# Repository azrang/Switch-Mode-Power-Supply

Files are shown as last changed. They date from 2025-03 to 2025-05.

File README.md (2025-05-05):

# Switch Mode Power Supply

This is a GitHub repo displaying all the files for the 2025 Cooper Union senior project, including the LTSpice simulations, firmware, testing procedures, and any final design files (block diagram, schematic, layout, etc.) for any boards manufactured. 

## Goals
The goal of this senior project is to make a Switch Mode Power Supply that can:
- Be SAFE (the 120V from the wall will be stepped down to 24V RMS using a transformer)
- Do AC-DC conversion so it can be used as a lab bench power supply
- Have 2 independent channels that range from 1-20V and 0-3A
- Support series and parallel mode for these channels
- Have a constant USB-C 5V 3A output
- Be power efficient
    - Based on the lab bench Gwinstek SMPS SPD-3606, a good target efficiency is 50%
- Low voltage ripple (<1%)

## Circuitry
Some of the circuitry for the project include:
- Safety Circuits
    - Common mode choke
    - Zener diodes
    - OVP
    - OCP
    - UVP
- Diode Rectifier
- Flyback converter
- Buck converter
- Opto-Isolators
- Power MOSFETs and power relays
- USB-C controller
- Feedback loop using an error amplifier
- 3 isolated grounds

## Firmware
Two ESP32 Dev Modules processing feedback and driving the circuit.

# Contributors
This project was done by a group of three friends:
- Azra Rangwala (EE'25)
- Ilona Lameka (EE'25)
- Ridwan Hussain (EE'25)

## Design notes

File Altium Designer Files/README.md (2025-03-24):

These are files from the Altium Designer for the Schematic and the Layout. 

- The "Board Information Report.txt" contains has information on the total number of components (352), connections (753), cooper utilization (87%, 91%, 92%, 92%), number of vias (289), etc.
- The "Project Outputs for SMPS.zip" is a final with all the gerber files that can be used to fabricate the board to manufacture the board. The settings chosen are specifically for JLC PCB.
- The "SMPS.zip" contains the Altium files (schematic, layout, etc.).
- The schematic was exported to the "SMPS_Schematic.pdf" file as a SmartPDF from Altium Designer so the nets are active links. 

# Layout
## Components 
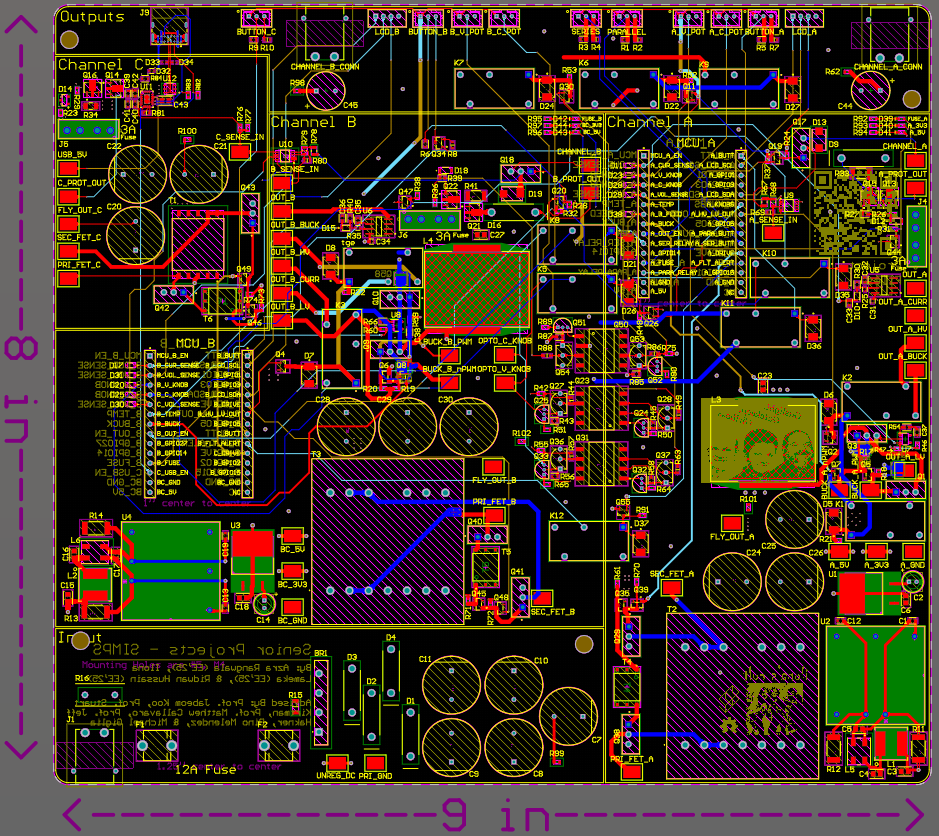
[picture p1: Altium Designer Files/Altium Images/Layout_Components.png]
Layout_Components


This image shows all the components and all the traces on the board.

## Top Layer
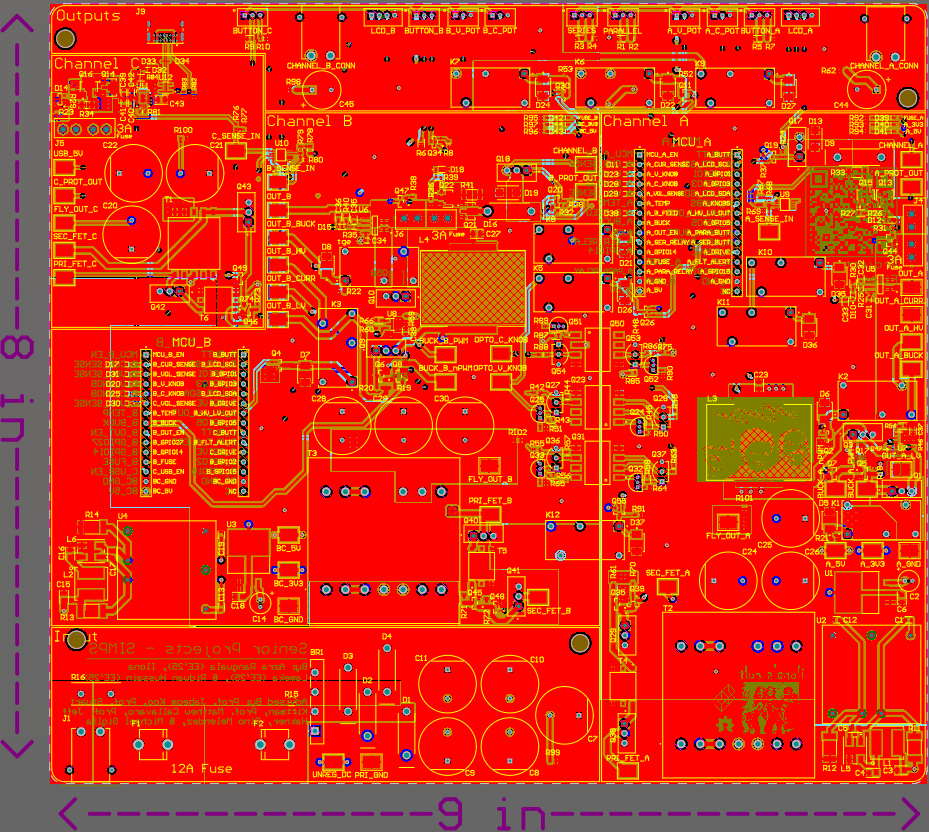
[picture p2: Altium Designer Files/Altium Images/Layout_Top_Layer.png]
Layout_Top_Layer


This image shows all of the top layer polygon pours.

## Layer 1
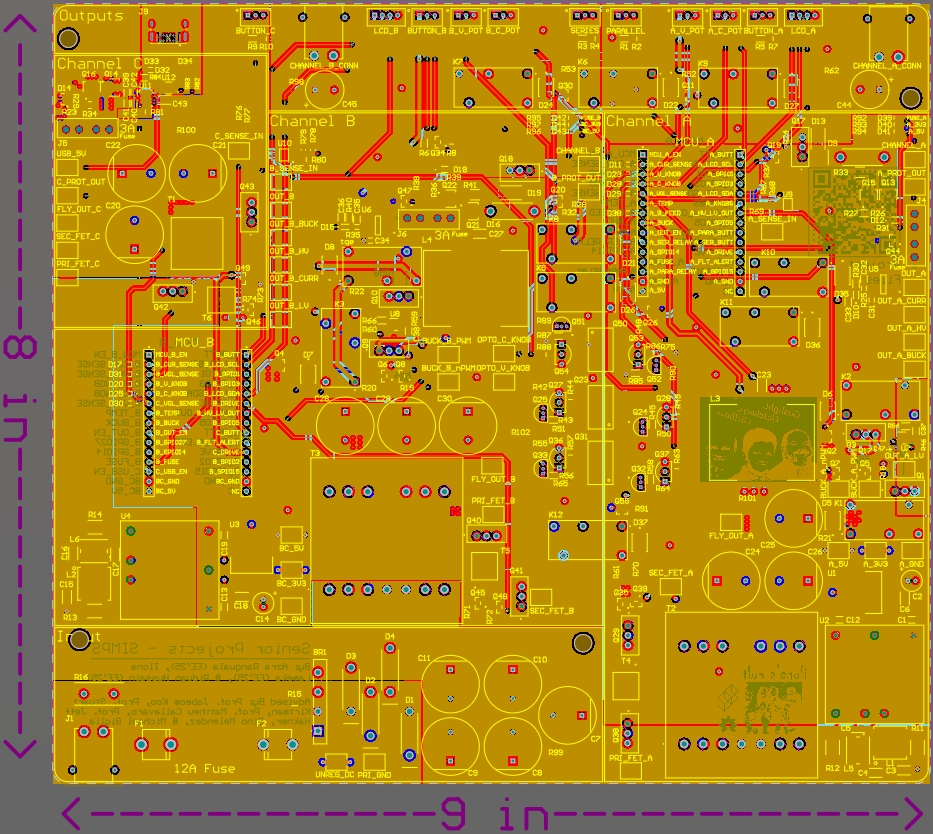
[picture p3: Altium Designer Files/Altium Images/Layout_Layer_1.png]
Layout_Layer_1


This image shows all of the layer 1 polygon pours.

## Layer 2
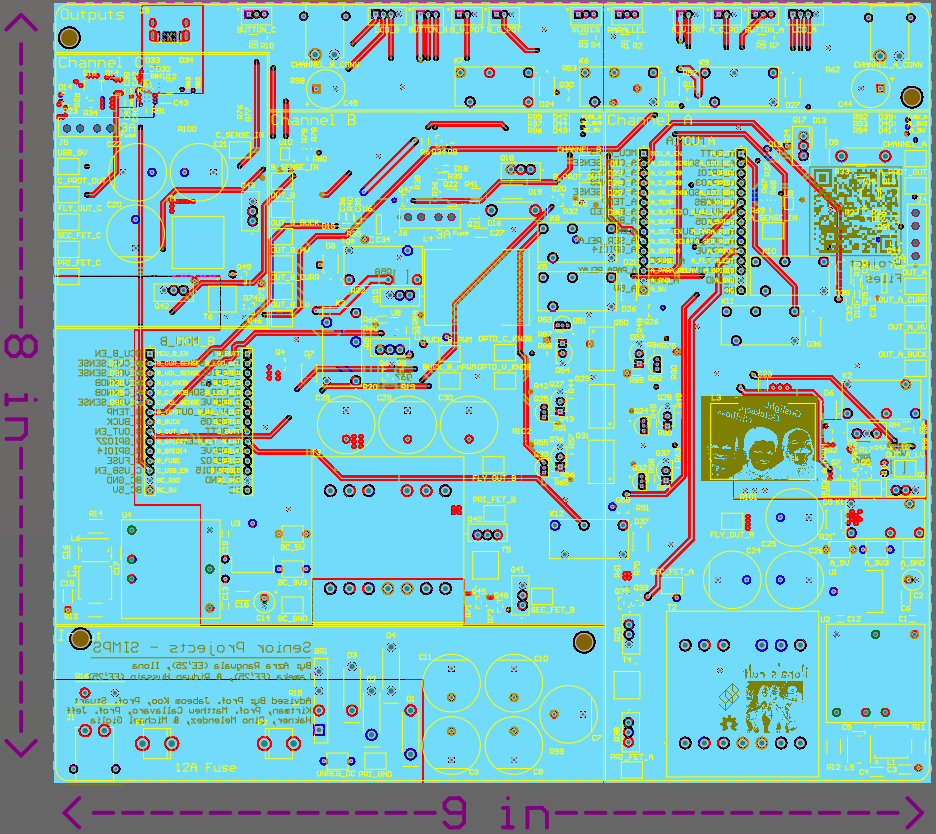
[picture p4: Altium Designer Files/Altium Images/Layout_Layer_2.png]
Layout_Layer_2


This image shows all of the layer 2 polygon pours.

## Bottom Layer
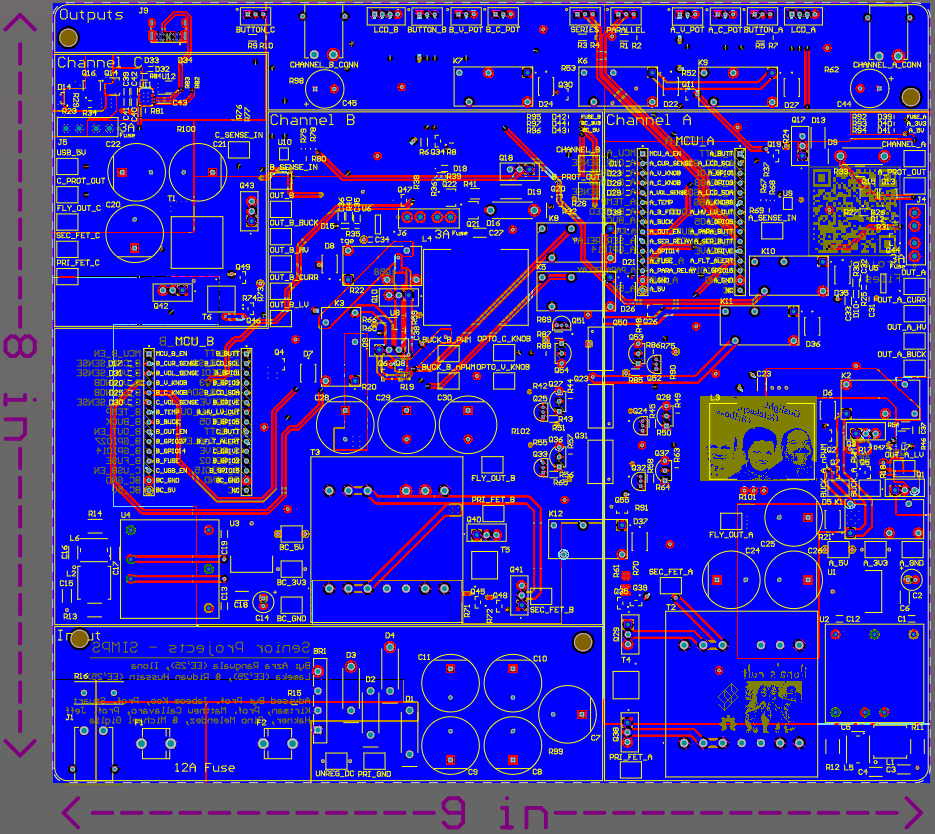
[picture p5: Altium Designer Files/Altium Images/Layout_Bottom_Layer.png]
Layout_Bottom_Layer


This image shows all of the bottom layer polygon pours.

## Top 3D View
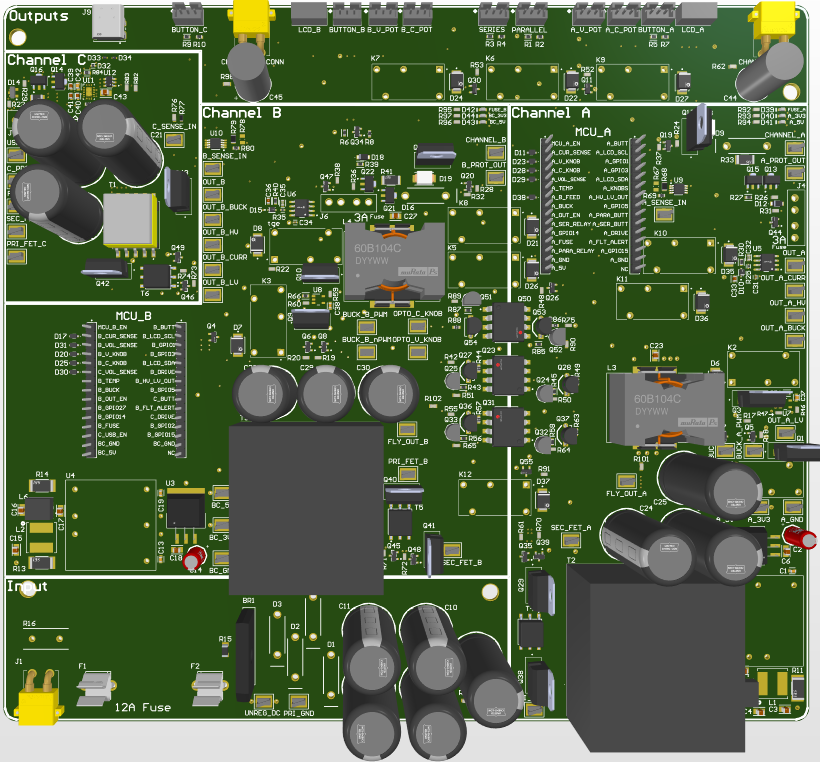
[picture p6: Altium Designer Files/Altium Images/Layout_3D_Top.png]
Layout_3D


This image shows the top 3D view of the board.

## Bottom 3D View
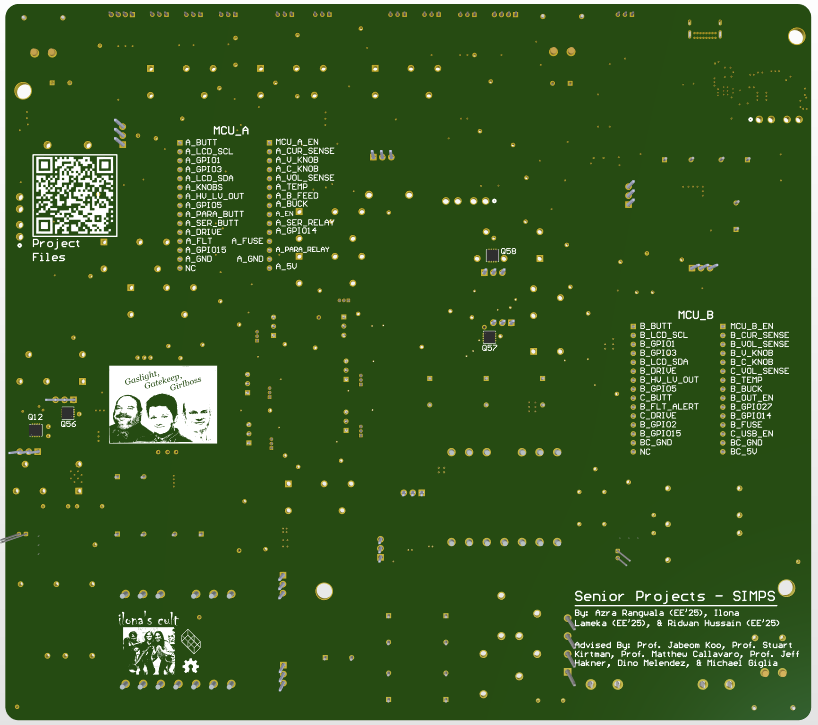
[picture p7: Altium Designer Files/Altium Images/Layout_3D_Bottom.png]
Layout_3D


This image shows the bottom 3D view of the board.

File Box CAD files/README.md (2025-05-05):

Onshape was used to design the CAD files for the box. 

1/4" clear acrylic was used.

Holes were cut to attach potentiometers, on/off buttons, LED screens, hinges, USBC port, etc.

A composite MDF base was used and the PCB was mounted on top of it. 

Here are the links to the onshape files:
- Top of Box: https://cad.onshape.com/documents/0df582968d671b375b7a9c29/w/103cd2e1ee54d52b4b8c83c5/e/ac7fc15e7fd9a07d4809bed0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 
- Sides: https://cad.onshape.com/documents/e65f365ee89599609901dbe1/w/213f92301eba854fda493029/e/9b6b9b5771b2472295cb6f8d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
- Front: https://cad.onshape.com/documents/9a4ddbb278e80e80a4dc2e93/w/c44b34705e7752b6a0ac6f8c/e/1b580939460691cddf3861bc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
- Back: https://cad.onshape.com/documents/6ed11a308b0e974dd588e9f7/w/b1c8eb4ebaca73d462ef1e77/e/57a0dc20c3867b08949bc04d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

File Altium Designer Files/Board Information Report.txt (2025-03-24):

Board Information Report
Date         : 3/23/2025
Time         : 5:12:02 PM
Time Elapsed : 00:00:01

General
    Board Size, 8999.997milsx7999.995mils
    Components on board, 352
count : 2

Routing Information
    Routing completion, 100.00%
    Connections, 753
    Connections routed, 753
    Connections remaining, 0
count : 4

Layer, Arcs, Pads, Vias, Tracks, Texts, Fills, Regions, ComponentBodies
    Top Layer, 0, 601, 0, 1095, 0, 0, 400, 0
    Layer 1, 0, 0, 0, 185, 0, 0, 51, 0
    Layer 2, 0, 0, 0, 172, 0, 0, 41, 0
    Bottom Layer, 0, 32, 0, 243, 0, 0, 74, 0
    Mechanical 1, 4, 0, 0, 4, 2, 0, 0, 27
    Top Assembly, 0, 0, 0, 496, 144, 0, 0, 3
    Bottom Assembly, 0, 0, 0, 0, 0, 0, 0, 0
    Top 3D Body, 14, 0, 0, 497, 0, 0, 0, 143
    Top Courtyard, 30, 0, 0, 514, 0, 0, 0, 0
    Bottom Courtyard, 0, 0, 0, 0, 0, 0, 0, 0
    Top Designator, 0, 0, 0, 0, 5, 0, 0, 0
    Bottom Designator, 0, 0, 0, 0, 0, 0, 0, 0
    Mechanical 10, 0, 0, 0, 24, 6, 0, 0, 0
    Top Component Outline, 7, 0, 0, 66, 0, 0, 2, 0
    Bottom Component Outline, 0, 0, 0, 24, 0, 0, 0, 0
    Mechanical 13, 57, 0, 0, 989, 2, 0, 0, 510
    Mechanical 15, 2, 0, 0, 1082, 0, 0, 20, 0
    Top Component Center, 0, 0, 0, 280, 0, 0, 0, 0
    Mechanical 20, 0, 0, 0, 12, 0, 0, 0, 0
    Bottom 3D Body, 0, 0, 0, 0, 0, 0, 0, 0
    Bottom Component Center, 0, 0, 0, 0, 0, 0, 0, 0
    Multi-Layer, 0, 367, 289, 0, 0, 0, 1, 0
    Top Paste, 0, 0, 0, 0, 0, 0, 2, 0
    Top Overlay, 160, 0, 0, 998, 780, 0, 0, 0
    Top Solder, 0, 0, 0, 0, 0, 0, 0, 0
    Bottom Solder, 0, 0, 0, 0, 0, 0, 4, 0
    Bottom Overlay, 3, 0, 0, 29, 78, 0, 1698, 0
    Bottom Paste, 0, 0, 0, 0, 0, 0, 4, 0
    Drill Guide, 0, 0, 0, 0, 0, 0, 0, 0
    Keep-Out Layer, 0, 0, 0, 0, 0, 0, 0, 0
    Drill Drawing, 0, 0, 0, 0, 0, 0, 0, 0
count : 31

Drill Pairs, Vias
    Top Layer - Bottom Layer, 289
count : 1

Layer, Sq.In., Sq.MM., Percent of layer
    Top Layer, 62.906, 40584.728, 87%
    Layer 1, 65.621, 42336.054, 91%
    Layer 2, 65.983, 42569.855, 92%
    Bottom Layer, 65.941, 42542.417, 92%
count : 4

Non-Plated Hole Size, Pads, Vias
    0mils, 48, 0
count : 1

Plated Hole Size, Pads, Vias
    0mils, 585, 0
    11.811mils, 0, 25
    15mils, 0, 173
    15.748mils, 16, 0
    20mils, 0, 6
    28mils, 0, 15
    30mils, 0, 64
    31.496mils, 49, 0
    35mils, 0, 2
    35.433mils, 4, 0
    37.402mils, 46, 0
    39.37mils, 14, 0
    40.158mils, 60, 0
    45mils, 12, 0
    50mils, 38, 0
    51.181mils, 60, 0
    57.48mils, 4, 0
    62.992mils, 26, 0
    65mils, 24, 0
    66.929mils, 6, 0
    77.953mils, 4, 0
    177.165mils, 0, 4
count : 22

Non-Plated Slot Size / Length, Pads
count : 0

Plated Slot Size / Length, Pads
    55.118mil / 23.622mil, 2
    82.677mil / 23.622mil, 2
count : 2

Non-Plated Square Hole Size, Pads
count : 0

Plated Square Hole Size, Pads
count : 0

Top Layer Annular Ring Size, Count
    -47.244mils, 2
    -19.685mils, 2
    3.937mils, 14
    5mils, 173
    8.189mils, 11
    9.843mils, 18
    9.843mils, 16
    10mils, 6
    12mils, 2
    19.685mils, 99
    20mils, 90
    21.654mils, 60
    22mils, 13
    25mils, 50
    25.591mils, 60
    28.74mils, 4
    31.496mils, 26
    33.465mils, 6
    41.339mils, 4
count : 19

Mid Layer Annular Ring Size, Count
    -47.244mils, 2
    -19.685mils, 2
    -5mils, 12
    3.937mils, 14
    5mils, 173
    8.189mils, 11
    9.843mils, 18
    9.843mils, 16
    10mils, 6
    12mils, 2
    15mils, 12
    19.685mils, 99
    20mils, 66
    21.654mils, 60
    22mils, 13
    25mils, 50
    25.591mils, 60
    28.74mils, 4
    31.496mils, 26
    33.465mils, 6
    41.339mils, 4
count : 21

Bottom Layer Annular Ring Size, Count
    -47.244mils, 2
    -19.685mils, 2
    3.937mils, 14
    5mils, 173
    8.189mils, 11
    9.843mils, 18
    9.843mils, 16
    10mils, 6
    12mils, 2
    19.685mils, 99
    20mils, 90
    21.654mils, 60
    22mils, 13
    25mils, 50
    25.591mils, 60
    28.74mils, 4
    31.496mils, 26
    33.465mils, 6
    41.339mils, 4
count : 19

Pad Solder Mask, Count
    0mils, 493
    1.496mils, 442
    1.772mils, 16
    1.969mils, 18
    2mils, 31
count : 5

Pad Paste Mask, Count
    -50.681mils, 1
    0mils, 999
count : 2

Pad Pwr/Gnd Expansion, Count
    15mils, 5
    20mils, 995
count : 2

Pad Relief Conductor Width, Count
    10mils, 1000
count : 1

Pad Relief Air Gap, Count
    10mils, 1000
count : 1

Pad Relief Entries, Count
    4, 1000
count : 1

Via Solder Mask, Count
    1.496mils, 283
    2mils, 6
count : 2

Via Pwr/Gnd Expansion, Count
    20mils, 289
count : 1

Track Width, Count
    1mils, 60
    1.969mils, 658
    3.937mils, 1330
    5mils, 378
    5.906mils, 24
    6mils, 178
    6.693mils, 6
    7.874mils, 2288
    8mils, 7
    8.268mils, 2
    9.526mils, 28
    9.526mils, 6
    10mils, 119
    15mils, 7
    15.748mils, 6
    18mils, 4
    20mils, 948
    25mils, 3
    28mils, 35
    30mils, 119
    35mils, 33
    40mils, 93
    50mils, 39
    55mils, 339
count : 24

Arc Line Width, Count
    0mils, 10
    1.969mils, 4
    2.756mils, 1
    3.937mils, 45
    5mils, 8
    5.906mils, 28
    7.874mils, 100
    9.843mils, 51
    19.685mils, 12
    20mils, 18
count : 10

Arc Radius, Count
    1.969mils, 30
    3mils, 4
    3mils, 2
    3mils, 4
    3.937mils, 56
    4.921mils, 51
    6.96mils, 1
    8mils, 2
    9.843mils, 12
    12mils, 6
    15mils, 10
    15.748mils, 3
    71.26mils, 2
    93.701mils, 12
    98.425mils, 2
    108.268mils, 2
    116.142mils, 2
    124.016mils, 6
    130mils, 4
    150mils, 4
    196.85mils, 4
    200.787mils, 2
    295.276mils, 28
    299.213mils, 28
count : 24

Arc Degrees, Count
    88, 8
    89, 8
    112, 6
    180, 82
    360, 173
count : 5

Text Height, Count
    27.559mils, 2
    33mils, 3
    35mils, 2
    39.37mils, 148
    40mils, 71
    50mils, 345
    59.055mils, 209
    60mils, 219
    80mils, 9
    100mils, 6
    250mils, 1
    300mils, 2
count : 12

Text Width, Count
    3mils, 2
    3.937mils, 148
    5mils, 2
    5.906mils, 5
    8mils, 68
    9mils, 350
    10mils, 420
    12mils, 9
    14mils, 1
    15mils, 4
    16mils, 1
    20mils, 5
    50mils, 2
count : 13

Net Track Width, Count
    4mils, 176
    10mils, 2
count : 2

Net Via Size, Count
    30mils, 178
count : 1

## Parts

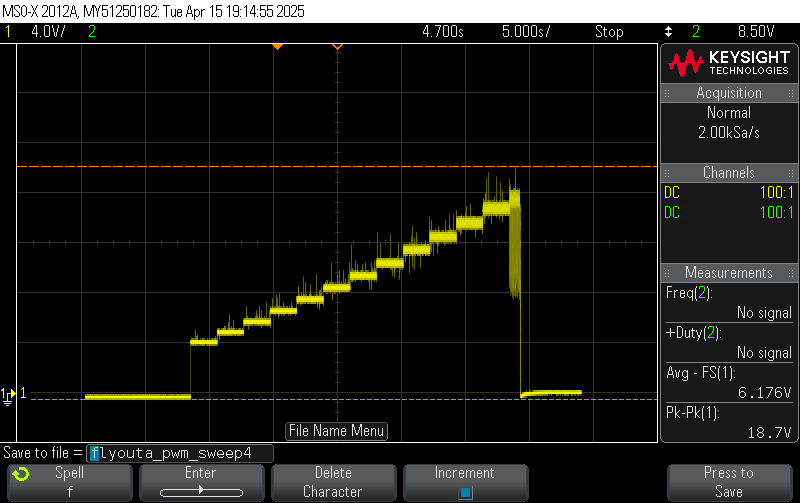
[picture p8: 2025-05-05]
Testing Materials/Images/flyouta_pwm_sweep4.bmp

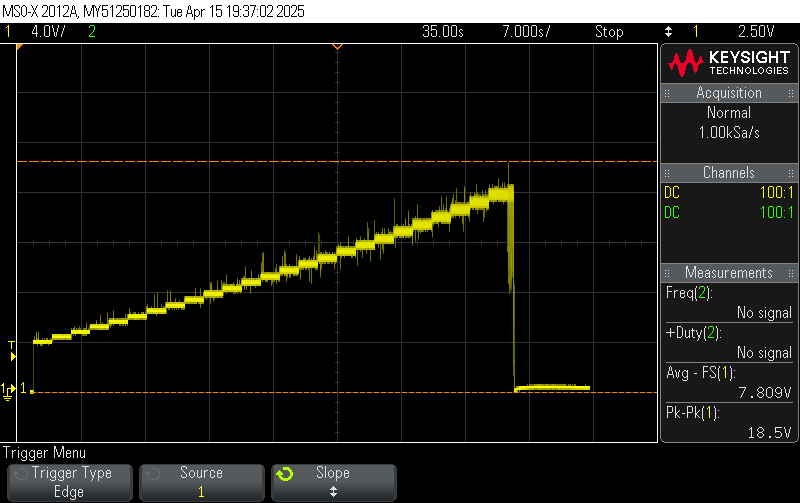
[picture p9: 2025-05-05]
Testing Materials/Images/flyouta_pwm_sweep5.bmp

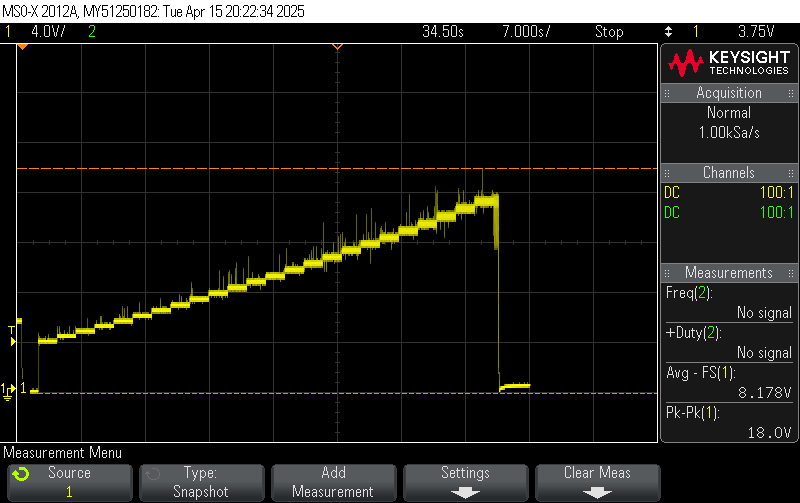
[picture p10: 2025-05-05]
Testing Materials/Images/flyouta_pwm_sweep7.bmp

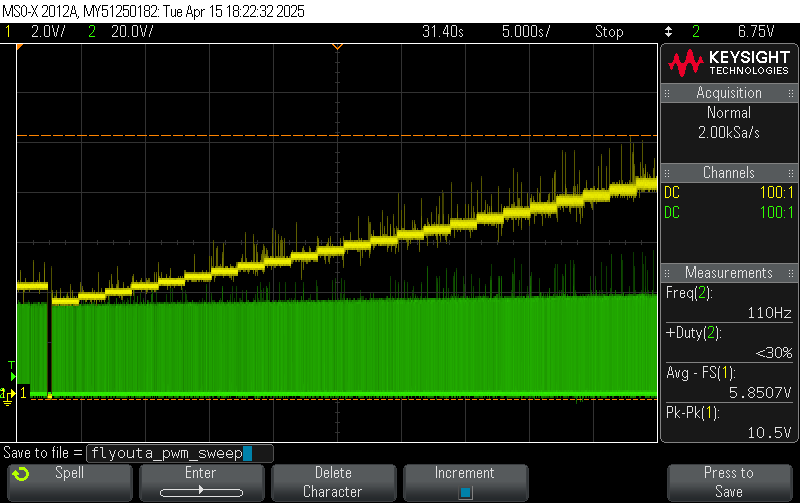
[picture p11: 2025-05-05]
Testing Materials/Images/flyouta_pwm_sweep1.bmp

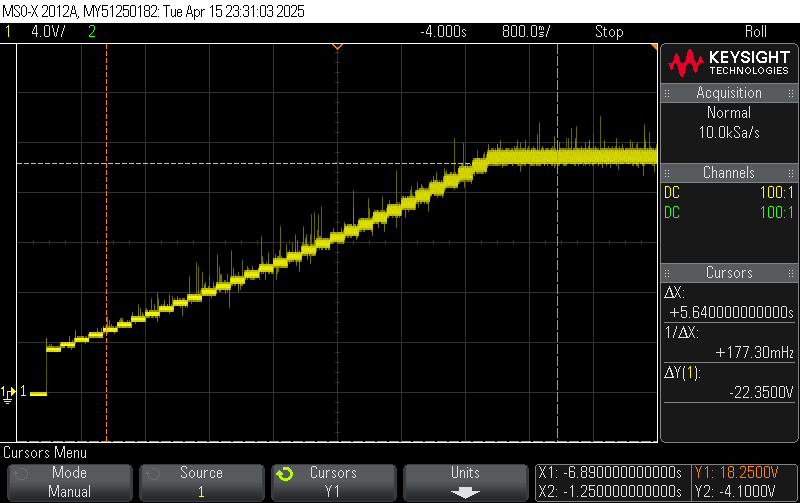
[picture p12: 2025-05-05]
Testing Materials/Images/flyouta_pwm_sweep18.png

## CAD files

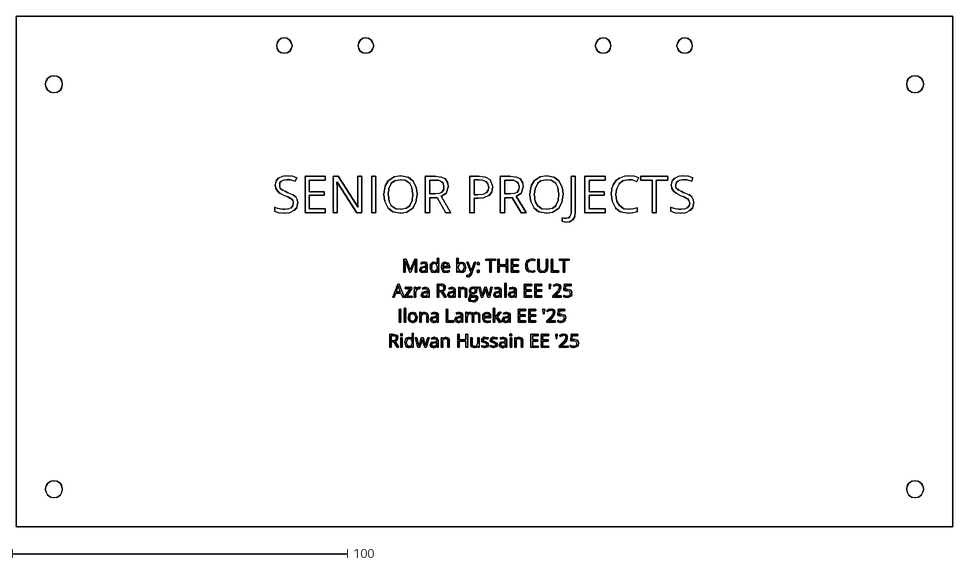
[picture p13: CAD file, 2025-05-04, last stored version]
Box CAD files/Part Studio 1 - Sketch 1 (6).dxf
279.4 x 152.4

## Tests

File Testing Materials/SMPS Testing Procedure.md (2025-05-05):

# General Notes
- General convention: 
	- Refdes will be displayed as **BOLD**
	- Test points (which are also typically net names) will be displayed as `NET_NAME`
	- MCU pins will also be displayed as *MCU Pins*.
	- Warning will be displayed as ***LIKE THIS***.
- All measurements will be done with 100x probe.
  	- There will be a consistent 450mV drop compared to the oscilloscope and digital multimeter readings.
- For Assembly, cut stencil up based on assembly order:
	- ***IF INTERACTING WITH LIVE CIRCUIT, WEAR HIGH VOLTAGE GLOVES***
- ***MINIMIZE*** the amount of interactions you have with live circuits and be wary of ***ARCS***.
- When soldering on components, make sure the circuit is disconnected.
- ***DO NOT TOUCH CAPACITORS ON THE CIRCUIT***
	- If you need to touch them for any reason, wait for them to discharge (based on the ***universal wait time*** which is determined below).
- ***DO NOT UPLOAD CODE TO THE ESP32 WHEN THE BOARD ROCKER SWITCH IS ON.***
	- Best practice is to take off the ESP32, upload the code, and then put it on.
        - Test scripts can be found in the Firmware/Test Scripts directory.

# 1. Input Circuit
1. This is to verify the input circuit does rectify the AC input.
2. Solder **BR1, F1, F2, J1, R15, R16, R99** and test points for `PRI_GND` & `UNREG_DC`.
	- Place a 12A FB fuse across **F1** & **F2**.
3. Test the input:
	- AC output on `UNREG_DC` with rocker switch OFF (no output)
	- AC output on `UNREG_DC` with rocker switch ON (Expected Full-Wave), recording the Vpp.
4. Desolder **BR1** and solder on **D1, D2, D3, D4**.
5. Test the input:
	- AC output on `UNREG_DC` with rocker switch OFF (no output)
	- AC output on `UNREG_DC` with rocker switch ON (Expected Full-Wave), recording the Vpp.
6. If the AC output for `UNREG_DC` has higher Vpp, then keep **D1, D2, D3, D4** on and move to step 6. Otherwise, desolder **D1, D2, D3, D4**, and solder on **BR1**. 
	- Verify the AC Output for `UNREG_DC` is the same as before if using **BR1** before continuing on.
7. Solder on **C7, C8, C9, C10, C11**.
8. Test the filtered input:
	- AC output on `UNREG_DC` (Expected near DC output, record ripple).
		- Can swap out capacitors with bigger value alternative capacitors from JLab to see if the rippling can be reduced significantly.
	- Check capacitor voltage is 0V after the rocker switch is OFF for 120 seconds.
		- This is the ***universal wait time*** for capacitors to discharge.
		- Note: Might need to wait longer if the capacitance was increased. 

# 2. Independent Channel A 
## Channel A LVDD
1. This is to test the `A_5V` & `A_3V3` rail.
2. Solder on **C1, C2, C3, C4, C5, C12, D41, L1, L5, R94, U2** and test points for `A_GND`, `A_5V`.
3. Check the `A_5V` rail.
	- DC output on `A_5V` (ripple less than 200mV) & the red LED is ON.
	- Verify `PRI_GND` & `A_GND` are isolated (using an ohmmeter). If not, go to step 4.
	- If output is clean, can skip to step 6. If not, go to step 4.
4. Desolder **C1, C3, C4, C5, C12, L1, L5** and solder on **R11, R12**.
5. Check the `A_5V` rail.
	- DC output on `A_5V` (ripple less than 200mV).
	- Verify `PRI_GND` & `A_GND` are isolated (using a voltmeter).
	- If output is cleaner, move on. If output is worst compared to before, revisit step 2.
		- If `GND`'s are now disconnected but worse output, LEAVE IT AS IS, and move on.
6. Solder on **C6, D40, U1, R93** & test point for `A_3V3`.
7. Check the `A_3V3` rail.
	- DC output on `A_3V3` (ripple less than 33mV) & the yellow LED is ON.

## Channel A ESP32
1. This is to test the ESP32 is powered on. 
2. Solder on **J7, J8**, or the header pins for the ESP32 MCU A.
3. Place the ESP32 on following the orientation on the board.
	- Verify the LED on the ESP32 module turns on.
4. Solder on **Q5, Q7, R17, R18** and test points `BUCK_A_nPWM`, `BUCK_A_PWM`, & `OUT_A_LV`.
5. Determine the accuracy of PWM duty cycle & logical level shift voltage levels.
	- Run the Channel_A_ESP32_PWM.cpp file.
		- Connect the `OUT_A_LV` to `A_5V` & measure this voltage.
		- Set the PWM to 10kHz with 10% duty cycle and measure how accurate the duty cycle is on the `BUCK_A_PWM` and `BUCK_A_nPWM` (should be 1 - duty cycle) & record the difference. This accuracy will be denoted as the *percent accuracy*.
			- Make sure that the logical levels for these circuits switches between `A_GND` & `A_5V`. 
		- Run these tests again in increasing order of 10kHz until you reach 50kHz and measure the *percent accuracy* for each frequency.

## Channel A External Connections Part 1
1. This is testing the input button & LCD screen for Channel A.
2. Solder on external JST connectors, **R5 & R7** for Channel A labelled **LCD_A, BUTTON_A**.
3. Test to make sure these connections work.
	- Run the Channel_A_Ext_Conn_1.cpp file.
		- Check to make sure the input from Button A is read properly on the LCD screen.

## Channel A Temperature Sensor
1. This is to test the temperature sensor.
2. Solder on **C37, R46, R47, U7**.
3. Solder on $50k\Omega$ for **R54**.
	- Run the Channel_A_Temp_Sense.cpp file.
		- Make sure the temperature sensor sends HIGH to *A_TMP_SNSE* at room temperature with this displayed on the LCD.
		- Make sure the temperature sensor sends a LOW signal with hot air gun at $55^{\circ}C$ (can set it up to $65^{\circ}C$) aimed at the temperature sensor and this is displayed on the LCD.
			- The temperature sensor should go off at around $53^{\circ}C$.
4. Determine what an appropriate resistor value for **R54** is to determine a temperature cut off.
	- Few choices here. Recommend using a lower temperature threshold first before moving onto higher threshold. Note this resistor value (will be used for Channel B later on).
		- $50k\Omega$ for $53^\circ C$ threshold
		- $30k\Omega$ for $79^{\circ}C$ threshold
		- $15k\Omega$ for $100^{\circ}C$ threshold

## Channel A Transformers
1. This is to test the flyback & feedback transformer. 
    - Note: This circuit needed some rework, so it WON'T be as simple as soldering on the components directly to the PCBs.
2. Solder on the following circuits so that the feedback transformer can work (read the "SMPS Testing Results.md" to see why this is necessary). 
    - Solder on a **$30k\Omega$** on the `UNREG_DC` **$24k\Omega$** on `PRI_GND`, creating a voltage division of 15.1V and a 10uF electrolytic capacitor at the voltage division. Can use the capacitor through hole mounts from **C7-C11** if they're available for the resistors.
    - Solder on the **UCC5304DWV** to the board. Use enamel wire to connect:
		- Pin 1: *A_DRIVE*
   		- Pin 2 & 3: *A_5V*
   		- Pin 4: *A_GND*
   		- Pin 5 & 6: *PRI_GND*
   		- Pin 7: the gate of Q29
   		- Pin 8: The 15.1V line made from the voltage division.
3. Test the new feedback transformer replacement circuit.
    - Run the Channel_A_Transformer_Gate.cpp file.
		- Verify there is 15.1V at this voltage division with little rippling.
    	- Verify that the *A_DRIVE* circuit is outputting a PWM signal at 50kHz with a 25% duty cycle.
     	- Verify that the gate of Q29, or pin 7 of the UCC5304DWV, is 50kHz 25% duty with a max voltage of 15.1V.
4. Solder on **C24, C25, C26, Q29, Q38, Q39, R70, R101, T2** and test points `FLY_OUT_A`, `PRI_FET_A` & `SEC_FET_A`.
5. Check the flyback transformer outputs VDC at `FLY_OUT_A`.
	- Run the Channel_A_Transformer1.cpp file.
		- With the MCU, send a fixed PWM at 10kHz with a duty cycle of 25% on *A_DRIVE* and record the VDC at `FLY_OUT_A` (should be approximately 10.9V $\pm$ 2V) & record how long it takes for the output to settle (call this *transformer settle time*).
			- ***MAKE SURE THE DUTY CYCLE IS BELOW 50% ALWAYS!!!***
			- Verify the frequency used has the expected VDC output, if not, repeat with a different frequency in increasing order of 10kHz.
				- Feel free to test in smaller increments like 5kHz, 1kHz, or 500Hz, but nothing smaller than 500Hz.
				- ***DO NOT GO ABOVE 50kHz!***
		- Verify one last time that `PRI_GND` and `A_GND` are isolated from each other (using an ohmmeter).
		- Check capacitor voltage is 0V after the rocker switch is OFF after the ***universal wait time***. 
		- If the ripple is above 50mV, change the **C24, C25, C26** to a higher capacitance after ***universal wait time*** and redo step 3.
6. Determine the duty cycle needed for 10V, 12V, 20V at `FLY_OUT_A`.
	- Edit and run the Channel_A_Transform1.cpp file.
		- Based on the previous step, determine at what duty cycle 10V, 12V, and 20V occurs at. Record these values as *minimum duty cycle*, *LV duty cycle*, & *maximum duty cycle*. 
7. Record PWM duty cycle vs. VDC output.
	- Run the Channel_A_Transformer2.cpp file.
		- Measure the output voltage, `FLY_OUT_A`, with the duty cycle sweeping across from *minimum duty cycle* & *maximum duty cycle* in the *percent accuracy* increments so the total interval is 50 seconds.
			- To measure the full sweeping waveform: 
				- Set the horizontal time div to 5s per block.
				- Use the trigger function so the entire waveform is captured in a 50 second window.
				- Measure each voltage by zooming into the horizontal waveform for each block or using a cursor.
				- This procedure will be used multiple times and will be referred to as a *sweep measurement*.
			- If duty cycle to voltage is nonlinear, use a line of best fit to estimate.
		- Some extra notes
			- The flyback transformer is expected to output 20V to 10V in normal operation. 
			- The 12V number will be used for LV circuit and WON'T change.
			- These ***won't*** be the final numbers for the min and max duty cycle for Channel A and PWM duty cycle, since there will be a voltage drop (i.e. there's a diode in line to prevent reverse polarity). 

## Channel A HV/LV 
1. This is to test the HV & LV relays + buck converter.
2. Solder on **C23, D5, D6, K1, K2, L3, Q2, Q12, Q56, R21** and test points `OUT_A_HV`,`OUT_A_BUCK`, and `OUT_A_CURR`.
3. Test HV side (through line).
	- Run the Channel_A_HV_SW.cpp file.
		- Send a LOW signal to *A_HV_LV_OUT*. 
		- Confirm that the input from `FLY_OUT_A` appears at `OUT_A_HV` and `OUT_A_CURR`. 
			- `OUT_A_LV` should be floating.
4. Test LV side (buck converter).
	- Run the Channel_A_LV_Buck1.cpp file.
		- Send a HIGH signal to *A_HV_LV_OUT* with `FLY_OUT_A` set to 12VDC and *A_BUCK* is set to 50% duty cycle at 10kHz.
			- Confirm you hear the relays click as the *A_HV_LV_OUT* changes.
			- Feel free to adjust the PWM frequency from 5kHz to 50kHz, but note longer frequencies will need more time for the transient to settle. 
		- Confirm that `FLY_OUT_A` and `OUT_A_LV` are both 12V. 
			- `OUT_A_HV` should be floating.
		- Confirm `OUT_A_BUCK` and `OUT_A_CURR` are the expected voltage (around 6V $\pm$ 1V).
			- If this isn't the case, move onto step 5. If it does work, move onto step 7.
5. Desolder **Q12, Q56** and solder on **Q1, Q3**. 
6. Run the tests from step 4 again.
7. Determine the duty cycle needed for 1V, 10V at `OUT_A_BUCK`.
	- Edit and run the Channel_A_LV_Buck1.cpp file.
		- Based on the previous step, determine at what duty cycle 1V and 10V occurs at. Record these values as *minimum buck duty cycle* & *maximum buck duty cycle*. 
		- If the ripple for the output of the buck converter is significant (more than 1%), then replace the **C23** capacitor. 
			- It might be necessary to use a 100uF/1mF through hole capacitor to get the voltage filtering desired.
	- Note: If the buck converter is not working properly, most of the voltage range can still be achieved by only using the flyback transformer (although the efficiency will be much worst compared to using a buck converter). 
8. Testing buck converter duty cycle vs. voltage output.
	- Run the Channel_A_LV_Buck2.cpp file.
		- Similar to the transformer, record the output voltage at `OUT_A_BUCK` with the duty cycle set from *minimum buck duty cycle* to *maximum buck duty cycle* in increments of *percent accuracy* so the total interval is 50 seconds and using the *sweep measurement*. 
			- If duty cycle to voltage is nonlinear, use a line of best fit to estimate.
		- Some extra notes
			- These ***won't*** be the final numbers used to associate output for Channel A and PWM duty cycle, since there will be a voltage drop (i.e. there's a diode in line to prevent reverse polarity). 
			- The buck converter is expected to output 10V to 1V in normal operation. Be wary when the output voltage is at the lower range since the buck converter can operate strange in the lower voltage ends.

## Channel A Current Sense & OVP
1. This is to test the current sense & OVP circuit.
2. Solder on **C31, C32, C33, D9, D10, D11, D12, D13, D39, J4, Q13, Q15, Q44, R25, R26, R27, R30, R31, R33, R92** and test points `OUT_A` and `A_PROT_OUT`.
3. Connect a $100\Omega$ resistor between `A_PROT_OUT` and `A_GND` and an ammeter between the fuse pins for **J4**.
4. Testing the current sense.
	- Run the Channel_A_CURR_SENSE.cpp file.
		- Set `OUT_A_CURR` to be 18V, 12V, 6V in 5s intervals.
		- Make sure the MCU displays the same current as the ammeter within a $\pm$ 0.10A tolerance (should be in the range of 0.18A, 0.12A, and 0.06A).
5. Replace the ammeter with a 3A fuse for **J4**.
6. Testing the OVP circuit.
	- Run the Channel_A_OVP.cpp file.
		- Set `OUT_A_CURR` to 20V by setting the duty cycle at the *maximum duty cycle*. 
			- Make sure that the output stays ON according to the current sense reading on the LCD screen. 
		- Set `OUT_A_CURR` to a voltage greater than 20V by setting the duty cycle to be *maximum duty cycle* + *percent accuracy*. 
			- Make sure that the output stays OFF according to the current sense reading on the LCD screen.

## Channel A Enable
1. This is testing Channel A enable.
2. Solder on **C44, Q17, Q19, R24, R37, R62** and test point `CHANNEL_A`.
3. Test the enable signal & voltage drop.
	- Run the Channel_A_Enable1.cpp file.
		- Send a LOW to *A_OUT_EN* and make sure `OUT_A` is giving a VDC output, but `CHANNEL_A` is low.
		- Send a HIGH to *A_OUT_EN* and make sure `OUT_A` and `CHANNEL_A` are nearly equal. 
			- Record the voltage drop across `FLY_OUT_A` and `CHANNEL_A`.
	- Make sure the **C44** is discharged after the ***universal wait time***.
4. Remap all the duty cycle to output voltage.
	- Run the Channel_A_Enable2.cpp file.
		- Determine the appropriate duty cycles needed for the flyback transformer & buck converter to output 1V - 20V at `CHANNEL_A`. 
			- Update the *minimum duty cycle*, *maximum duty cycle*, *minimum buck duty cycle*, and *maximum buck duty cycle*, but NOT the *LV duty cycle*.
		- NOTE: The circuit should switch from HV to LV when the voltage at `CHANNEL_A` reads 10V, not when `FLY_OUT_A` 10V. 

## Channel A Feedback
1. This is to test the feedback signal from Channel A output.
2. Solder on **D29, R67, R68, R69, U9** and test point `A_SENSE_IN`.
3. Test the feedback signal.
	- Run the Channel_A_Feedback.cpp file.
		- Map the output voltages measured at `CHANNEL_A` to the ADC readings (displayed on the LCD screen) at 1V intervals. 
		- Make a line of best fit to determine the relationship between ADC reading and voltage output.
	- With this new mapping, the MCU should use *A_VOL_SENSE* as the actual voltage and adjust *A_DRIVE* (or *A_BUCK*) accordingly.

## Channel A External Connections Part 2
1. This is testing the input potentiometer & XT30 connector for `CHANNEL_A`.
2. Solder on external JST connectors for Channel A labelled **A_V_POT, A_C_POT** and the XT30 connecter, **CHANNEL_A_CONN**.
3. Test to make sure the potentiometers work.
	- Run the Channel_A_Ext_Conn2.cpp file.
		- The pot inputs do adjust their respective voltage (1V-20V) and current values (0A-3A) and it is displayed on the LCD screen.
4. Test to make sure the `CHANNEL_A` XT30 connector works.
	- Run the Channel_A_Ext_Conn3.cpp file.
		- Set the `CHANNEL_A` output to be 1V, 6V, 12V, and 20V. 
		- Measure the `CHANNEL_A` output at the end of the XT30 connector and verify the ripple is below 20mV. 
			- If the ripple is greater than 20mV, increase the capacitance for **C44** and test again.

## Channel A Testing
1. This is to make sure Channel A is working properly independently. 
	- The file used to run all these tests should be the final Channel A code used to run the power supply (only needs to support independent channel at this point, doesn't need to support series or parallel mode yet), so they should all be the same.
2. Testing output voltage with load.
	- Verify that the power is able to set an output of 1V, 6V, 12V, and 20V with a 1kOhm resistor connected.
3. Test the voltage regulation
	- Set the output voltage to 12V with (no load).
	- Add a 1kOhm resistor while the power supply is running and measure to see if there is any significant transient changes in the voltage and current. 
	- Set the output voltage to 6V and rerun the same test (no load then attach a 1kOhm resistor while it's running).
4. Testing power supply at maximum and minimum range.
	- Rerun the same test from step 3, but with the output voltage set to 1V and 20V.
5. Make sure the HV/LV relays are robust.
	- Set the voltage to 9.9V, 10V, 10.1V and that voltage appears at `CHANNEL_A` and the XT30 connector (no load).
	- Attach a load while the power supply is running and see if there is any significant transient changes in voltage/current and if it can handle transient changes near the edge of the voltage changes. 
6. Make sure the current can be set from 0-3A.
	- Disconnect the fuse and connect an ammeter in series to make sure the output current matches the `CHANNEL_A` output current LCD screen reading.
		- Set a current limit to 0.10A with the voltage to 6V and connect the output to a $100\Omega$ resistor to make sure the output current is correct within a $\pm$ 0.01A, and there's 6V across Channel A.
		- Set a current limit to 0.03A with the voltage to 6V and connect the output to a $100\Omega$ resistor to make sure the current limit turns on, and there's no output across Channel A.
7. Testing 0V output.
	- It is possible to set the output voltage to a voltage lower than 1V due to the forward drop of the diode. 
	- Lower the duty cycle of the buck converter until you notice what the absolute minimum is based on either:
		- The duty cycle is too low (don't go below 5% duty cycle).
		- The ripple it too large to be filtered and reach voltage ripple spec.
8. Leave the power supply on for 30 mins to make sure no overheating. 
	- For the following tests, make sure the power supply doesn't overheat, and the voltage stays accurate for the entire 60 min duration (check on it every 5-10 minutes).
	- Set the voltage to 20V and connect no load. 
	- Set the voltage to 10V and connect no load.
	- Set the voltage to 20V and connect $100\Omega$ resistor.
	- Set the voltage to 10V and connect $100\Omega$ resistor.
	- Set the voltage to 12V and connect $20\Omega$ resistor (need power resistor).
	- Set the voltage to 10V and connect $20\Omega$ resistor (need power resistor).

---
# 2. Independent Channel B
## Some Notes
- This will be mostly identical to independent channel A except the refdes for the components will change to their channel B counterparts and some minor tweaks to the testing. 
- Most of the test results should yield similar results to Channel A. ***IF THEY DON'T VERIFY WHY BEFORE MOVING ON.***
- Most of the scripts used should be the same logic as the channel A (for independent test at least), but make sure to double check the pins for all tests. Some of the pins are different across the two channels, namely: *B_VOL_SENSE*, *B_V_KNOB*, *B_C_KNOB*, *B_TEMP*, *B_DRIVE*. 

## Channel B LVDD
1. This is to test the `B_5V` & `B_3V3` rail.
2. Solder on the same set of components as Channel A (**C13, C14, C15, C16, C17, C19, D44, L2, L6, R97, U4** OR **C14, R11, R12**) and test points for `B_GND`, `B_5V`. 
3. Check the `B_5V` rail.
	- DC output on `B_5V` (ripple less than 200mV) & the red LED is ON (similar to Channel A).
	- Verify `PRI_GND` & `B_GND` are isolated (using an ohmmeter).
4. Solder on **C18, D43, U3, R96** & test point for `B_3V3`.
5. Check the `B_3V3` rail.
	- DC output on `B_3V3` (ripple less than 33mV) & the yellow LED is ON.

## Channel B ESP32
1. This is to test the ESP32 is powered on. 
2. Solder on **J10, J11**, or the header pins for the ESP32 MCU B.
3. Place the ESP32 on following the orientation on the board.
	- Verify the LED on the ESP32 module turns on.
4. Solder on **Q6, Q8, R19, R20** and test points `BUCK_B_nPWM`, `BUCK_B_PWM`, & `OUT_B_LV`.
5. Determine the accuracy of PWM duty cycle & logical level shift voltage levels.
	- Run the Channel_B_ESP32_PWM.cpp file.
		- Connect the `OUT_B_LV` to `B_5V` & measure this voltage.
		- Set the PWM to 10kHz with 10% duty cycle and measure how accurate the duty cycle is on the `BUCK_B_PWM` and `BUCK_B_nPWM` (should be 1 - duty cycle) & record the difference. This accuracy will be denoted as the *percent accuracy*.
			- Make sure that the logical levels for these circuits switches between `B_GND` & `B_5V`. 
		- Run these tests again in increasing order of 10kHz until you reach 50kHz and measure the *percent accuracy* for each frequency.

## Channel B External Connections Part 1
1. This is testing the input button & LCD screen for Channel B.
2. Solder on external JST connectors for Channel B labelled **LCD_B, BUTTON_B**.
3. Test to make sure these connections work.
	- Run the Channel_B_Ext_Conn_1.cpp file.
		- Check to make sure the input from Button B is read properly on the LCD screen.

## Channel B Temperature Sensor
1. This is to test the temperature sensor.
2. Solder on **C38, R59, R60, U8**.
3. Solder on $50k\Omega$ for **R66**.
	- Run the Channel_B_Temp_Sense.cpp file.
		- Make sure the temperature sensor sends HIGH to *B_TMP_SNSE* at room temperature with this displayed on the LCD.
		- Make sure the temperature sensor sends a LOW signal with hot air gun at $55^{\circ}C$ (can set it up to $65^{\circ}C$) aimed at the temperature sensor and this is displayed on the LCD.
			- The temperature sensor should go off at around $53^{\circ}C$.
4. Solder on the same resistor for **R66** as used in **R54**. 

## Channel B Transformers
1. This is to test the flyback & feedback transformer.
2. Solder on **C28, C29, C30, Q40, Q41, Q45, Q48, R71, R72, R102, T3, T5** and test points `FLY_OUT_B`, `PRI_FET_B` & `SEC_FET_B` (use the same values for **C28, C29, C30** as you did for **C24, C25, C26**).
3. Check the flyback transformer outputs VDC at `FLY_OUT_B`.
	- Run the Channel_B_Transformer1.cpp file.
		- With the MCU, send a fixed PWM at the same frequency for *B_DRIVE* as *A_DRIVE* for the transformer with a 25% duty cycle. Record the VDC at `FLY_OUT_B` (should be approximately 10.9V $\pm$ 2V) & record how long it takes for the output to settle (call this *transformer settle time*).
			- ***MAKE SURE THE DUTY CYCLE IS BELOW 50% ALWAYS!!!***
		- Verify one last time that `PRI_GND`, `A_GND`, and `B_GND` are all isolated from each other (using an ohmmeter).
		- Check capacitor voltage is 0V after the rocker switch is OFF after the ***universal wait time***. 
4. Determine the duty cycle needed for 10V, 12V, 20V at `FLY_OUT_B`.
	- Edit and run the Channel_B_Transform1.cpp file.
		- Based on the previous step, determine at what duty cycle 10V, 12V, and 20V occurs at. Record these values as *minimum duty cycle*, *LV duty cycle*, & *maximum duty cycle*.
		- Make sure these duty cycles are very close to the duty cycles found in Channel A, if not the same.
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

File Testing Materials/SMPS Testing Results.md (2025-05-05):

The screenshots of the waveforms were taken on a MSO-X 2012A oscilloscope.

# 1. Input Circuit

1. Soldered **BR1, F1-F2, J1, R15-R16, R99** from the *Input* and test points for `PRI_GND` & `UNREG_DC`. Place 12A fuse.
   	- AC output on `UNREG_DC` with rocker switch OFF: No Output
   	- AC output on `UNREG_DC` with rocker switch ON:
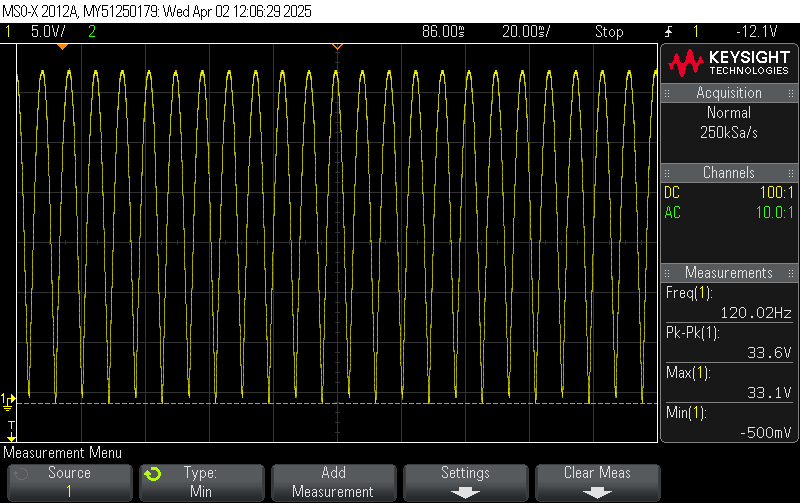
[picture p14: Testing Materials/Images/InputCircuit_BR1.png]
InputCircuit_BR1
	
2. Desoldered **BR1** and solder on **D1-D4** from the *Input*.
	- AC output on `UNREG_DC` with rocker switch OFF: No Output
	- AC output on `UNREG_DC` with rocker switch ON:
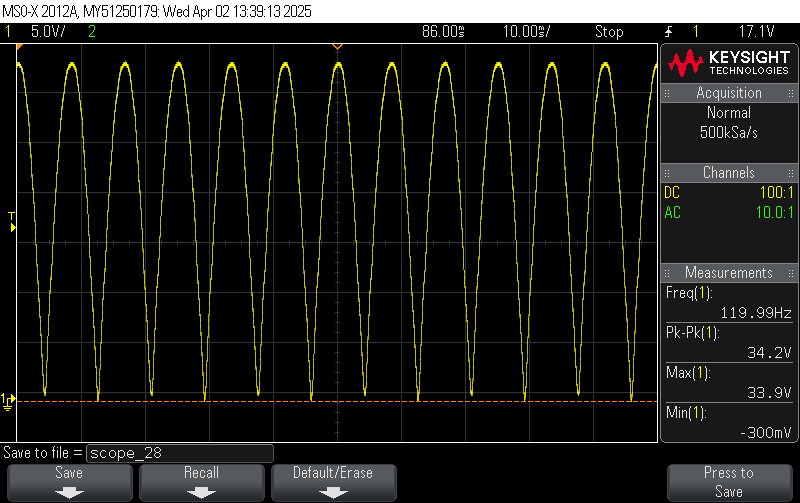
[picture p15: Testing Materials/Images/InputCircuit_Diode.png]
InputCircuit_Diode
	
3. **BR1** vs **D1-D4** results: **D1-D4** had a lower voltage drop compared to **BR1**. Will continue with **D1-D4** for future testing.

4. Tested AC input waveform.
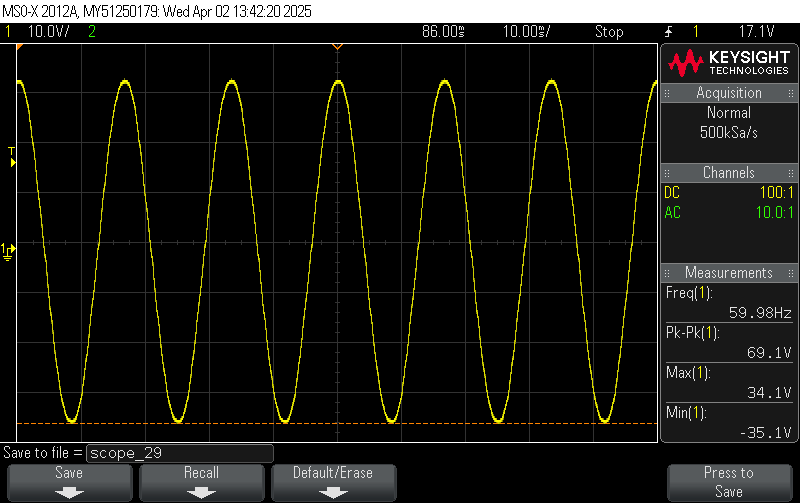
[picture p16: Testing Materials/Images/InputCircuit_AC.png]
InputCircuit_AC
	

5. Soldered on **C9-C11** from the *Input*.
6. Tested the filtered input:
	- AC output on `UNREG_DC`: 33.8V DC output, less than 0.5% ripple.
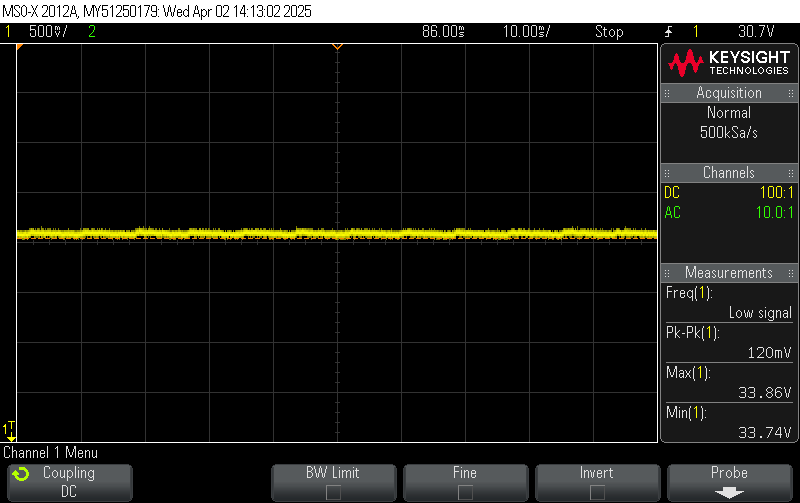
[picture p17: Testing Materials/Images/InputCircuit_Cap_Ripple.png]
InputCircuit_Cap_Ripple
	
	- Capacitor discharged to 0V after 60 seconds after rocker switch is OFF.

# 2. Independent Channel A 
## Channel A LVDD
1. This is to test the `A_5V` & `A_3V3` rail.
2. Soldered on **C1, C3, C4, C5, C12, D41, L1, L5, R94, U2** from the *LVDD* and test points for `A_GND`, `A_5V`.
3. Checked the `A_5V` rail.
	- DC output on `A_5V` had ringing noise at a frequency of 42 kHz.
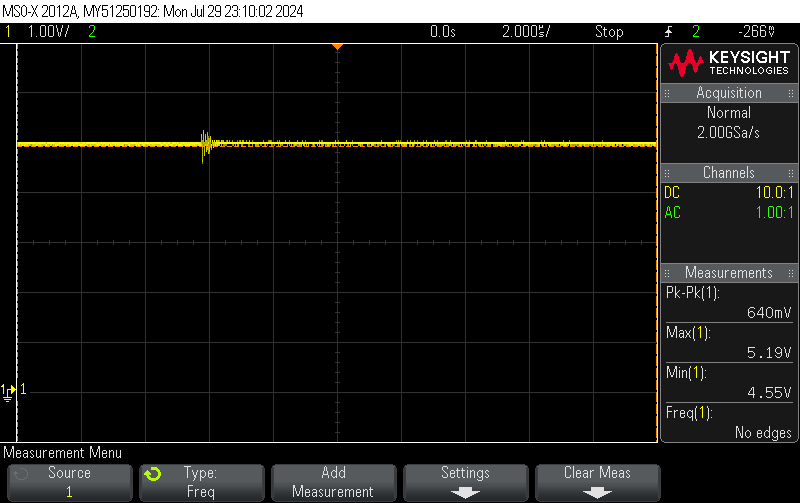
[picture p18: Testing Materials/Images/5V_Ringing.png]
5V_Ringing
  	
  	- 5V red LED turned on.
	- Ignoring the ringing, the `A_5V` net has a max of 4.99V and a min 4.91V
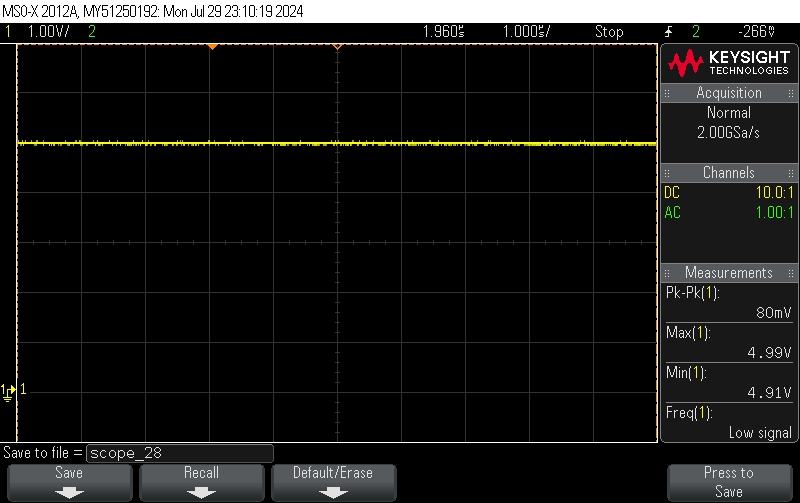
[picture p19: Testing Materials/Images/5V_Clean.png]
5V_Clean
  	
	- `PRI_GND` & `A_GND` are isolated (using a voltmeter, ohmmeter, and continuity check).
4. Soldered on **C2, C6, D40, U1, R93** & test point for `A_3V3` from the *LVDD*.
5. Checked the `A_5V` rail again.
   	- DC output on `A_5V` had an average output of 4.87V. The ringing was reduced with the **C2** capacitor.
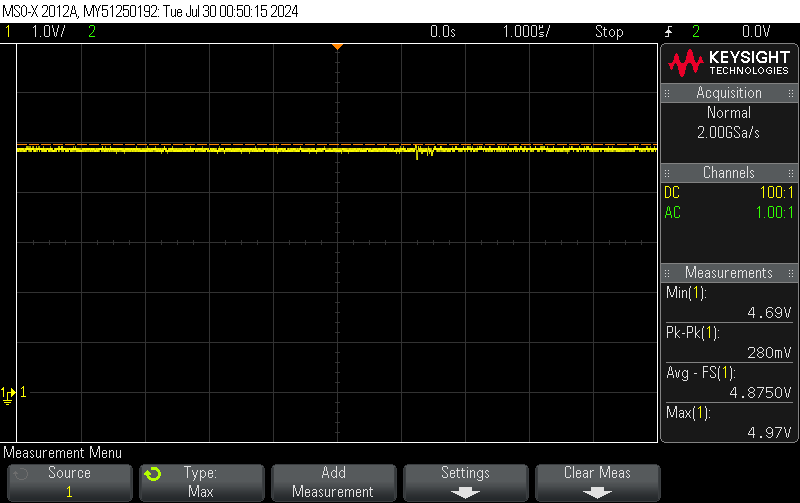
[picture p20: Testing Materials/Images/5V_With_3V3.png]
5V_With_3V3
   	  
7. Checked the `A_3V3` rail.
	- DC output on `A_3V3` had an average output of 3.17V.
	- 3V3 yellow LED turned on.
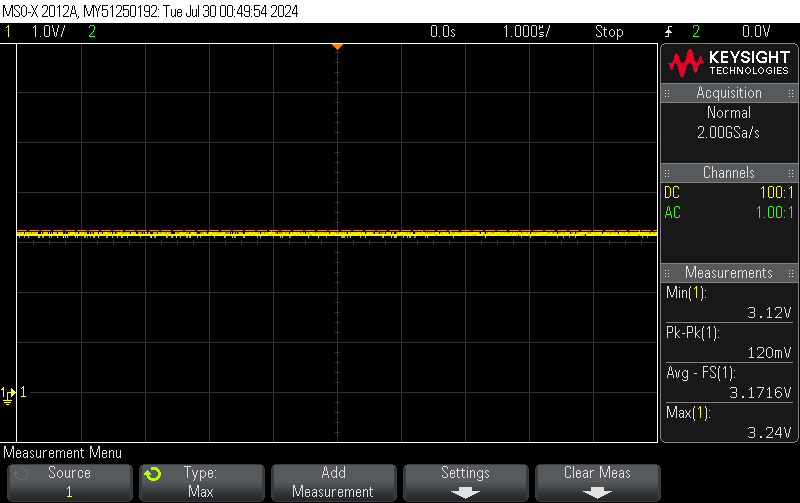
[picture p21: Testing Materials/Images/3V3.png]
3V3
	

## Channel A ESP32
1. Tested the ESP32 powers on. 
2. Soldered on **J7, J8**.
3. Placed the ESP32 on the board.
	- LED on the ESP32 turned on.
4. Soldered on **Q5, Q7, R17, R18** and test points `BUCK_A_nPWM`, `BUCK_A_PWM`, & `OUT_A_LV`.
5. Determined the accuracy of PWM duty cycle & logical level shift voltage levels.
	- Ran the Channel_A_ESP32_PWM.cpp file.
		- The PWM was set to 10kHz with a 10% duty cycle. `BUCK_A_PWM` showed exactly 10% and `BUCK_A_nPWM` had 90%. The PWM from the ESP32 has an accurate duty cycle.
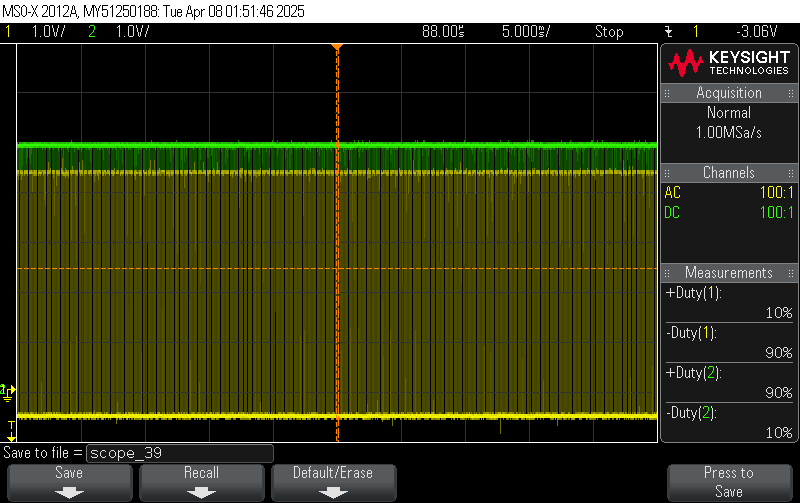
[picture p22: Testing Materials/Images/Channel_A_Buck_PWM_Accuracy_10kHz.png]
Channel_A_Buck_PWM_Accuracy_10kHz
		
			- Logical level shifts between `A_GND` & `A_5V` for `BUCK_A_PWM` and`BUCK_A_nPWM` at 10kHz.
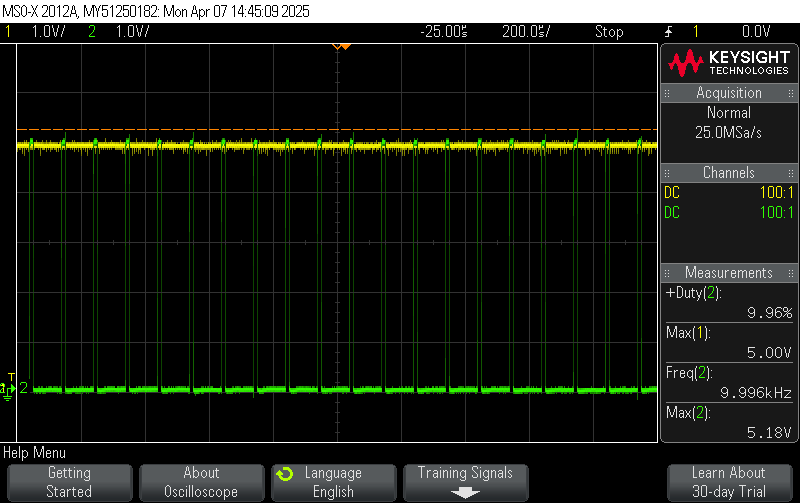
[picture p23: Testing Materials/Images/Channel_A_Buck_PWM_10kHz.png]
Channel_A_Buck_PWM_10kHz
   		 	
     			Channel_A_Buck_nPWM_10kHz
     
	- Test was then run for 50kHz.
		- The PWM was set to 50kHz with a 10% duty cycle. `BUCK_A_PWM` showed approximately 10% and `BUCK_A_nPWM` had 90%. The PWM is accurate also at 50kHz.
		Channel_A_Buck_PWM_Accuracy_50kHz
			- Logical level shifts between `A_GND` & `A_5V` for `BUCK_A_PWM` and`BUCK_A_nPWM` at 50kHz.
   		 	Channel_A_Buck_PWM_50kHz
     			Channel_A_Buck_nPWM_50kHz

## Channel A External Connections Part 1
1. Tested the input button & LCD screen for Channel A.
2. Soldered on external JST connectors, **R5 & R7** for Channel A labelled **LCD_A, BUTTON_A**.
3. Tesedt to make sure these connections work.
	- Ran the Channel_A_Ext_Conn_1.cpp file.
		- LCD correctly displayed BUTTON LOW or BUTTON HIGH depending on the button state.
   		- The button itself also lit up the internal LED.

## Channel A Temperature Sensor
1. Tested the temperature sensor.
2. Soldered on **C37, R46, R47, U7**.
3. Soldered on $51k\Omega$ for **R54**.
	- Ran the Channel_A_Temp_Sense.cpp file.
		- Used a hot air gun set at $100^{\circ}C$. Temperature sensor sent LOW to *A_TMP_SNSE* when the hot air gun was pointed at it. Temperature sensor sent HIGH in room temperature.
		- The temperature sensor should go off at around $52^{\circ}C$.
4. Finalized on a resistor value for **R54** is to determine a temperature cut off.
	- $50k\Omega$ for $53^\circ C$ threshold.

## Channel A Transformers
1. This is to test the flyback & feedback transformer. 
    - An issue was found with the switching MOSFET **Q35** and its pull up resistor **R61**. Due to the low resistance of the feedback transformer, the output would never be pulled up to 5V through the **R61** resistor. To fix this, an isolated gate driver (UCC5304DWV) was purchased to replace **Q35, R61 & T4**. The isolated gate driver accepts the MCU PWM input and outputs it to the gate of **Q38** on the primary side.
    	- The isolated gate driver has a noticable issue where the output voltage does not match the VDD provided on the primary side of the isolation. A significant voltage drop is noticed, which will need to be addressed.
    - Another issue was noticed with the dot polarity of the transformer. The architecture for the flyback converter required opposing dot polarities, which were missed during the schematic phase of the project. To fix this, the pins for `SEC_FET_A` and `FLY_OUT_A` were swapped by soldering on jumper wires.
    - Snubbers were also added to **Q29 & Q38**. Both transistors got a capacitor and resistor across their drain and source pins. **Q38** had a resistor of $22\Omega$ and a capacitor of 680pF, while **Q29** had a resistor of $15\Omega$ and capacitor of 680pF. The snubbers were found on an online [Snubber Calculator](https://biricha.com/tools-and-downloads/flyback-rc-snubber-design/).
    - We also changed the pull up resistor **R70** from $1k \Omega$ to $150 \Omega$.
    - The filter capacitors on `FLY_OUT_A` were also changed to three 470uF, a 1uF and a 47nF capacitors. After numerous testing, the finalized values for the capacitors were 10pF + 100pF + 47nF + 1uF + 470uF + 1mF + 2.2mF.
    - After multiple fuses being blown when attempting to reach a higher output voltage on `FLY_OUT_A`, it was found that a "soft start" is required, where we begin with a lower duty cycle and transition to a higher one after a certain time delay.
    - New ways of verifying damaged components were found, such as tests for transformers, MOSFETs, and ISO driver.
2. Soldered on the following circuits so that the feedback transformer can work.
    - Soldered on a $8.2k\Omega$ on the `UNREG_DC` and a $6.8k\Omega$ on `PRI_GND`, creating a voltage division of 15.1V, along with a 10uF elecotrlytic capacitor at the voltage division.
    - Soldered on the **UCC5304DWV** to the board. Use enamel wire to connect:
    	- Pin 1: `A_DRIVE`
     	- Pin 2 & 3: `A_5V`
      	- Pin 4: `A_GND`
      	- Pin 5 & 6: `PRI_GND`
      	- Pin 7: the gate of **Q29**
      	- Pin 8: The 15.1V line made from the voltage division.
3. Tested the new feedback transformer replacement circuit.
    - Ran the Channel_A_Transformer_Gate.cpp file.
		- 10-11V Output (Probably loading effect). PWM signal at 50kHz with a 25% duty cycle at 10V.
4. Soldered on **C24, C25, C26, Q29, Q38, Q39, R70, R101, T2** and test points `FLY_OUT_A`, `PRI_FET_A` & `SEC_FET_A`.
	- Ran the Channel_A_Transformer1.cpp file.
		- Smoke came out immediately, the `PRI_GND` copper exploded and continuity between the ground plane was gone. The 5V buck was also damaged. Also removed **Q29, Q38**.
   		- Added a new buck and a `PRI_GND` wire. Circuit worked fine without running the PWM output.
		- Added new **Q29, Q38** transistors and ran the script again. Smoke once again came from the thermistor and transformer. 12A fuse was blown. Circuit is pulling too much current.
	- Also noticed that the previous PCB also had damage to the `PRI_GND` trace.
5. After multiple frequency and duty tests were ran it was found that as the switching frequency increases, the maximum `FLY_OUT_A` voltage decreases. This means that a "buzzing" sound is heard the higher the duty cycle is set to. However, the overall voltage ripple decreases as the frequency increases. By decreasing the frequency, the "buzzing" sound will be heard at a higher frequency.
   - A frequency of 42kHz was finalized for the transformer after multiple tests were ran. The available duty cycles were also set to 10%-40% which translates to `FLY_OUT_A` voltages of 3.35V-18.78V. The minimum time delay between stepping up the duty cycle was determined to be 1% per 0.1s in the code, or 1% per 0.18s after measured on the oscilloscope.
   - The graph below displays a snapshot of the flyout transformer output (yellow).
	04-25_test7_flyout_new_caps_zoomed_out

## Channel A HV/LV 
1. Tested the HV & LV relays + buck converter on a bare board.
2. Soldered on **C23, D5, D6, K1, K2, L3, Q2, Q12, Q56, R21** and test points `OUT_A_HV`,`OUT_A_BUCK`, and `OUT_A_CURR`.
3. Used a clean 12VDC input for the bare board.
4. Tested HV side (through line).
	- Ran the Channel_A_HV_SW.cpp file.
		- Sent a LOW signal to *A_HV_LV_OUT*. 
		- Relays switched and the input from `FLY_OUT_A` disappeared from `OUT_A_HV`. 
5. Tested LV side (buck converter).
	- Ran the Channel_A_LV_Buck1.cpp file.
		- Sent a LOW signal to *A_HV_LV_OUT* with `FLY_OUT_A` set to 12VDC and *A_BUCK* is set to 50% duty cycle at 10kHz.
			- Relays clicked as the *A_HV_LV_OUT* changed.
			- A high pitch buzzing sound was heard as soon as the relays switched and the buck converter was being used.
		- Confirmed that `FLY_OUT_A` and `OUT_A_LV` are both 12V. 
			- `OUT_A_HV` was floating.
		- Confirmed `OUT_A_BUCK` and `OUT_A_CURR` were around 5.69V. There was a 10kHz ripple throughout the output, with a peak-to-peak of 1.1V. High ripple had to be reduced.

   		buck_10khz_50duty_z
6. Determined the duty cycle needed for 1V, 10V at `OUT_A_BUCK`.
	- Edited and ran the Channel_A_LV_Buck1.cpp file.
		- Duty cycle 1V and 10V occurs: *9.75%* & 88.86%* maximum buck duty cycle or in terms of bit duty cycle (100 & 910).
   		- High ripple on the output voltages.
7. Made edits to reduce the overall ripple.
 	- Increased frequency to 35kHz from 10kHz for a lower ripple.
	- Added $1k\Omega$ parallel resistor to **R17 & R18** to decrease overall resistance. Got a clearer PWM on `BUCK_A_PWM` and `BUCK_A_nPWM` which increased its duty cycle. This also reduced the ripple voltage.
  	- New clean 12VDC 35kHz, 50% duty cycle results:
      buck_35khz_50dutypwm
     bbuck_35khz_50duty
8. Tested and assembled on actual board. Added the additional pull up resistors in parallel with **R17 & R18**.
9. Tested LV and HV side.
 	- There is a strong ripple after the buck starts driving the transformer input. Usually lasts for a maximum of 15 seconds and then settles to a lower ripple. Frequency does not affect the ripple time, nor does starting with a large voltage and decreasing or a low voltage and increasing the buck output voltage. It was found that 1% per 100ms is better  than 3% per 200ms for the buck PWM control. Based on how long the circuit was discharged for, the spikes last less.
 	 - Large ripple needs to be addressed, possibly snubbers, smaller caps etc.
10. Added additional capacitors to reduce the rippling on the buck converter.
	 - The final cap values on the buck circuit are: 10pF, 10uF, and 47uF.
  	 - This is what the final output looks like for the buck converter circuit @ 35kHz and 50% duty cycle (green is buck converter, yellow is flyout transformer).
04-25_test8_buck_new_caps_zoomed_out

## Channel A Current Sense & OVP
1. Tested the current sense & OVP circuit on a bare board. (She Died)
2. Soldered on **C31, C32, C33, D9, D10, D11, D12, D13, J4, Q13, Q15, Q44, R25, R26, R27, R30, R31, R33** and test points `OUT_A` and `A_PROT_OUT`.
3. Connected a $11.2\Omega$ 10W power resistor between `A_PROT_OUT` and `A_GND` and an ammeter between the fuse pins for **J4**.
4. Tested the current sense.
	- Ran the Channel_A_CURR_SENSE.cpp file.
		- Recorded the ADC bit values compared to a multimeter measurement for voltages ranging from 1-20V. Mostly linear results, around 25mA tolerance on the accuracy of the current readings. (Expected 10mA accuracy).
5. Tested the OVP circuit on a bare board. (She Died)
 	- Soldered a wire shorting **D9**.
	- Run the Channel_A_CURR_SENSE.cpp file (just using it to ignore the buck converter circuit).
  		- Injected voltage into `FLY_OUT_A`, probing `OUT_A` and `A_PROT_OUT` to see the result of OVP.
 		- OVP was triggered when `FLY_OUT_A` was set to 22.05V.
		- Voltage drop between `OUT_A` and `A_PROT_OUT` was around 100mV without OVP triggered.
6. Tested the current sense on real board. Huge ripple was observed with a 20 ohm power resistor. Current was also too low for the current sense to get accurate readings. Decision was made to use only high output resistance loads and to not use current sense.
   	- Higher current leads to higher buzzing.
  
## Channel A Enable
1. Tested Channel A enable. (She Died)
2. Soldered on **C44, Q17, Q19, R24, R37, R62** and test point `CHANNEL_A`.
   	- Problem was noticed with the circuit, **Q17** would have an improper $$V_{GS}$$. When the gate is driven low, the circuit operates correctly with no output voltage at `CHANNEL_A`. However, when the gate was driven high, the source would reach a higher voltage than the gate, effectively making the **Q17** fail as a switch since it is an NMOS. To solve this, a relay was soldered on to act as the switch instead of the stated components..
3. Tested the enable signal & voltage drop.
	- Ran the Channel_A_Enable1.cpp file.
		- Sent a LOW to *A_OUT_EN*: `OUT_A` is giving a VDC output, but `CHANNEL_A` is low.
		- Sent a HIGH to *A_OUT_EN*:`OUT_A` and `CHANNEL_A` are nearly equal. 
			- Voltage drop across `FLY_OUT_A` and `CHANNEL_A`: 50mV-100mV
	- Make sure the **C44** is discharged after the ***5s***.
4. Tested Channel A enable on real board.
5. Soldered on the relay circuit, worked.

## Channel A Feedback
1. This is to test the feedback signal from Channel A output.
2. Solder on **D29, R67, R68, R69, U9** and test point `A_SENSE_IN`.
3. Test the feedback signal.
	- Ran the Channel_A_Feedback.cpp file. Voltage_Feedback
		- Mapped the output voltages measured at `A_PROT_OUT` to the ADC readings (displayed on the LCD screen).
  - Voltage_Feedback

---

## Channel B LVDD
1. Tested the `B_5V` & `B_3V3` rail.
2. Soldered on the same set of components as Channel A (**C13, C14, C15, C16, C17, C19, D44, L2, L6, R97, U4**) and test points for `B_GND`, `B_5V`. 
3. Checked the `B_5V` rail.
	- The yellow LED is ON (similar to Channel A).
	- Verify `PRI_GND` & `B_GND` are isolated (using an ohmmeter).
4. Soldered on **C18, D43, U3, R96** & test point for `B_3V3`.
5. Checked the `B_3V3` rail.
	- The red LED is ON.
 	- Screenshot showing BC_5V and BC_3V3 waveforms:
	bc_lvdd

## Channel B ESP32
1. This is to test the ESP32 is powered on. 
2. Solder on **J10, J11**, or the header pins for the ESP32 MCU B.
3. Place the ESP32 on following the orientation on the board.
	- Verify the LED on the ESP32 module turns on.
4. Solder on **Q6, Q8, R19, R20** and test points `BUCK_B_nPWM`, `BUCK_B_PWM`, & `OUT_B_LV`
   	- Added $1k\Omega$ parallel resistor to **R19 & R20** to decrease overall resistance.
   	- Waveform of the logical level shift circuits can be seen in the waveform (yellow and green are NOT'd of each other).
   	b_buck_pwm_acc_35khz
6. Determine the accuracy of PWM duty cycle & logical level shift voltage levels.
	- Run the Channel_B_ESP32_PWM.cpp file.
		- Connect the `OUT_B_LV` to `B_5V` & measure this voltage.
		- Set the PWM to 10kHz with 10% duty cycle and measure how accurate the duty cycle is on the `BUCK_B_PWM` and `BUCK_B_nPWM` (should be 1 - duty cycle) & record the difference. This accuracy will be denoted as the *percent accuracy*.
			- Make sure that the logical levels for these circuits switches between `B_GND` & `B_5V`. 
		- Run these tests again in increasing order of 10kHz until you reach 50kHz and measure the *percent accuracy* for each frequency.
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

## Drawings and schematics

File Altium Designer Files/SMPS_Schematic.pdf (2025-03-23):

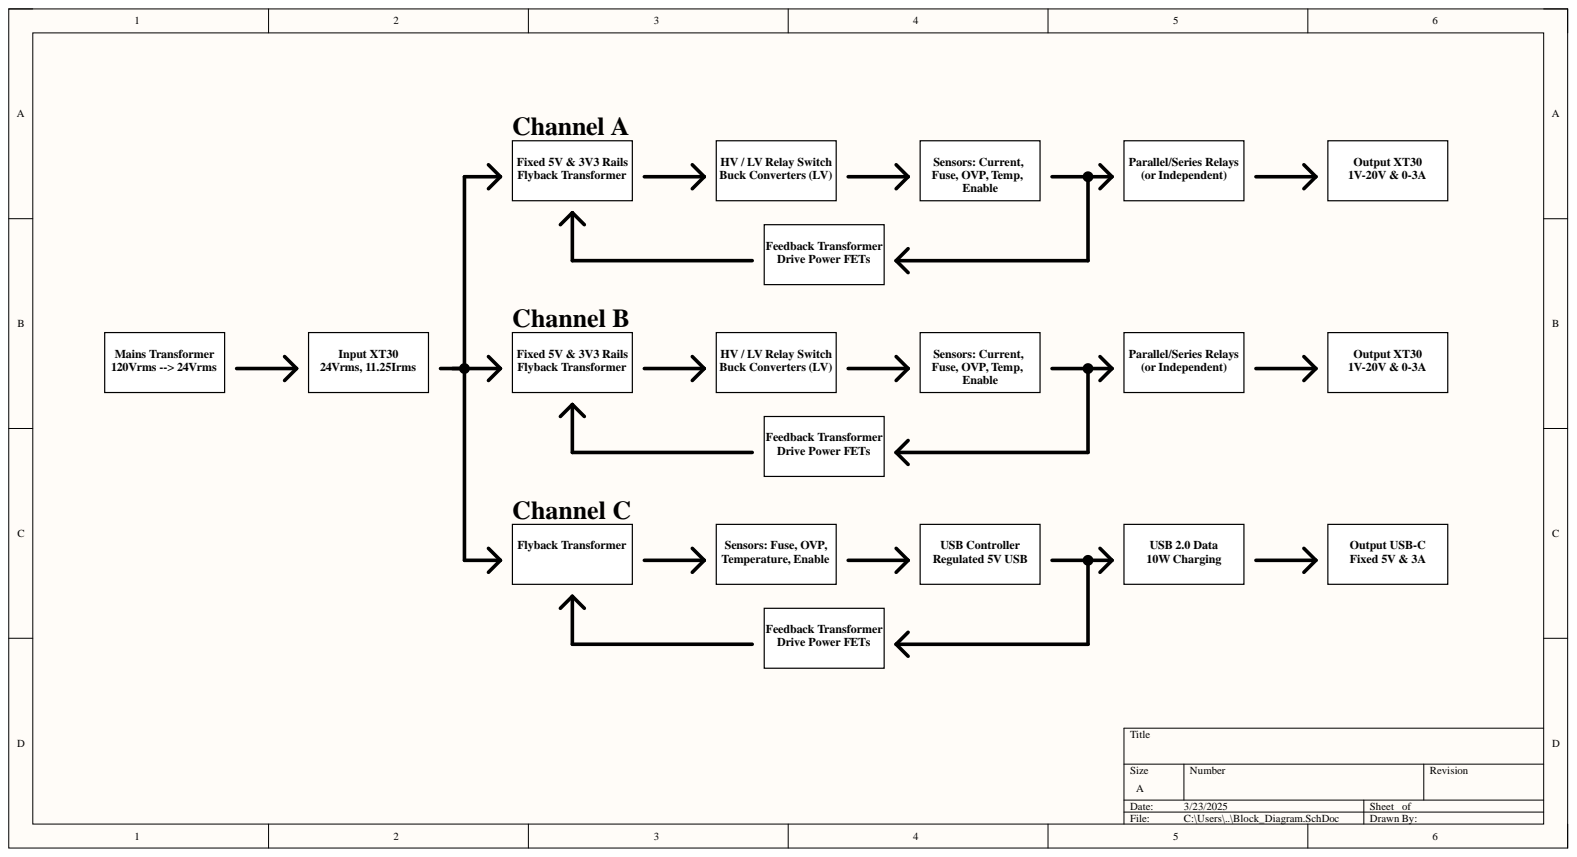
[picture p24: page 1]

HV / LV Relay Switch
Buck Converters (LV)

Size A | Number | Revision

Date: 3/23/2025 | Sheet of
File: C:\Users\..\Block_Diagram.SchDoc | Drawn By:

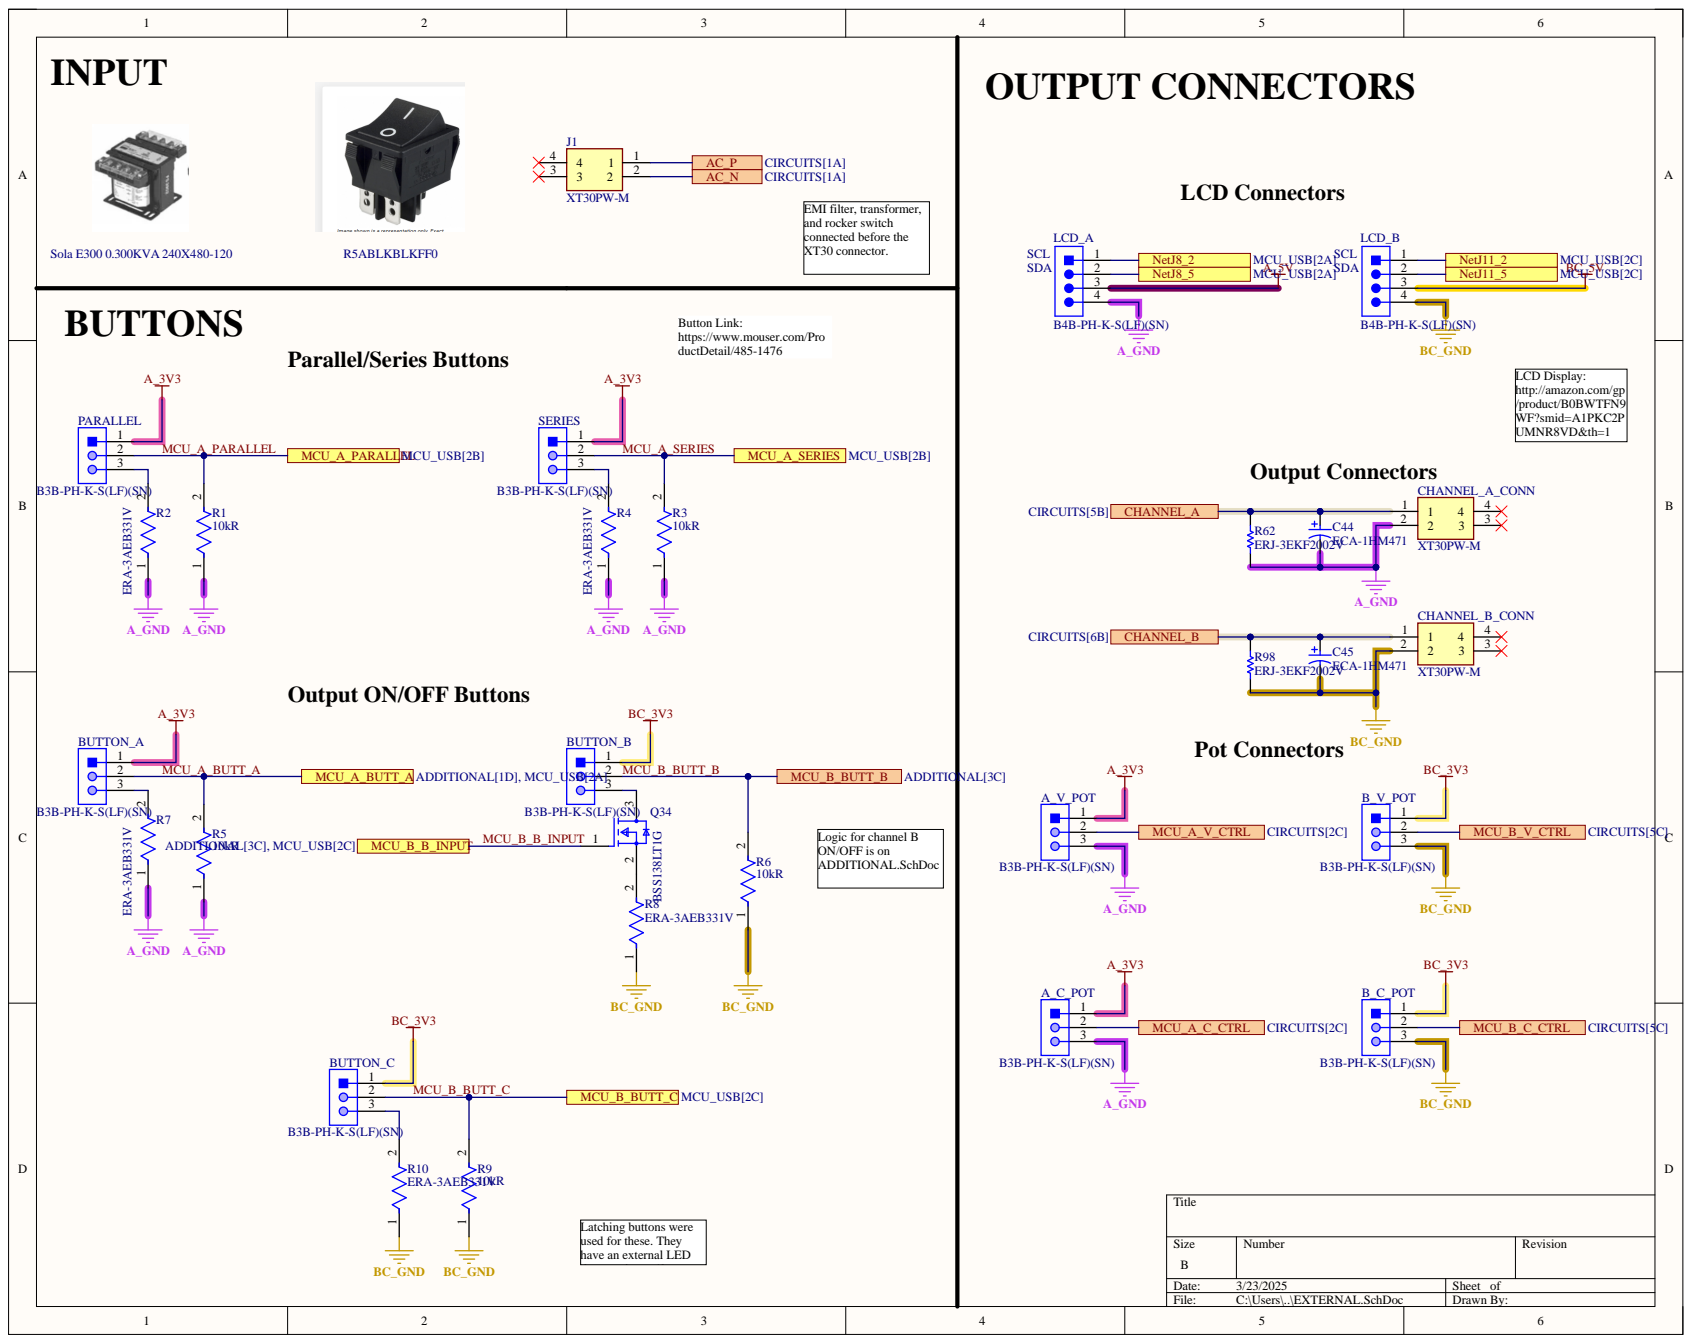
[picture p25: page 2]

Button Link:
https://www.mouser.com/Pro

LCD Display:
http://amazon.com/gp
/product/B0BWTFN9
WF?smid=A1PKC2P
UMNR8VD&th=1

Output ON/OFF Buttons

Logic for channel B
ON/OFF is on
ADDITIONAL.SchDoc

Latching buttons were
used for these. They
have an external LED

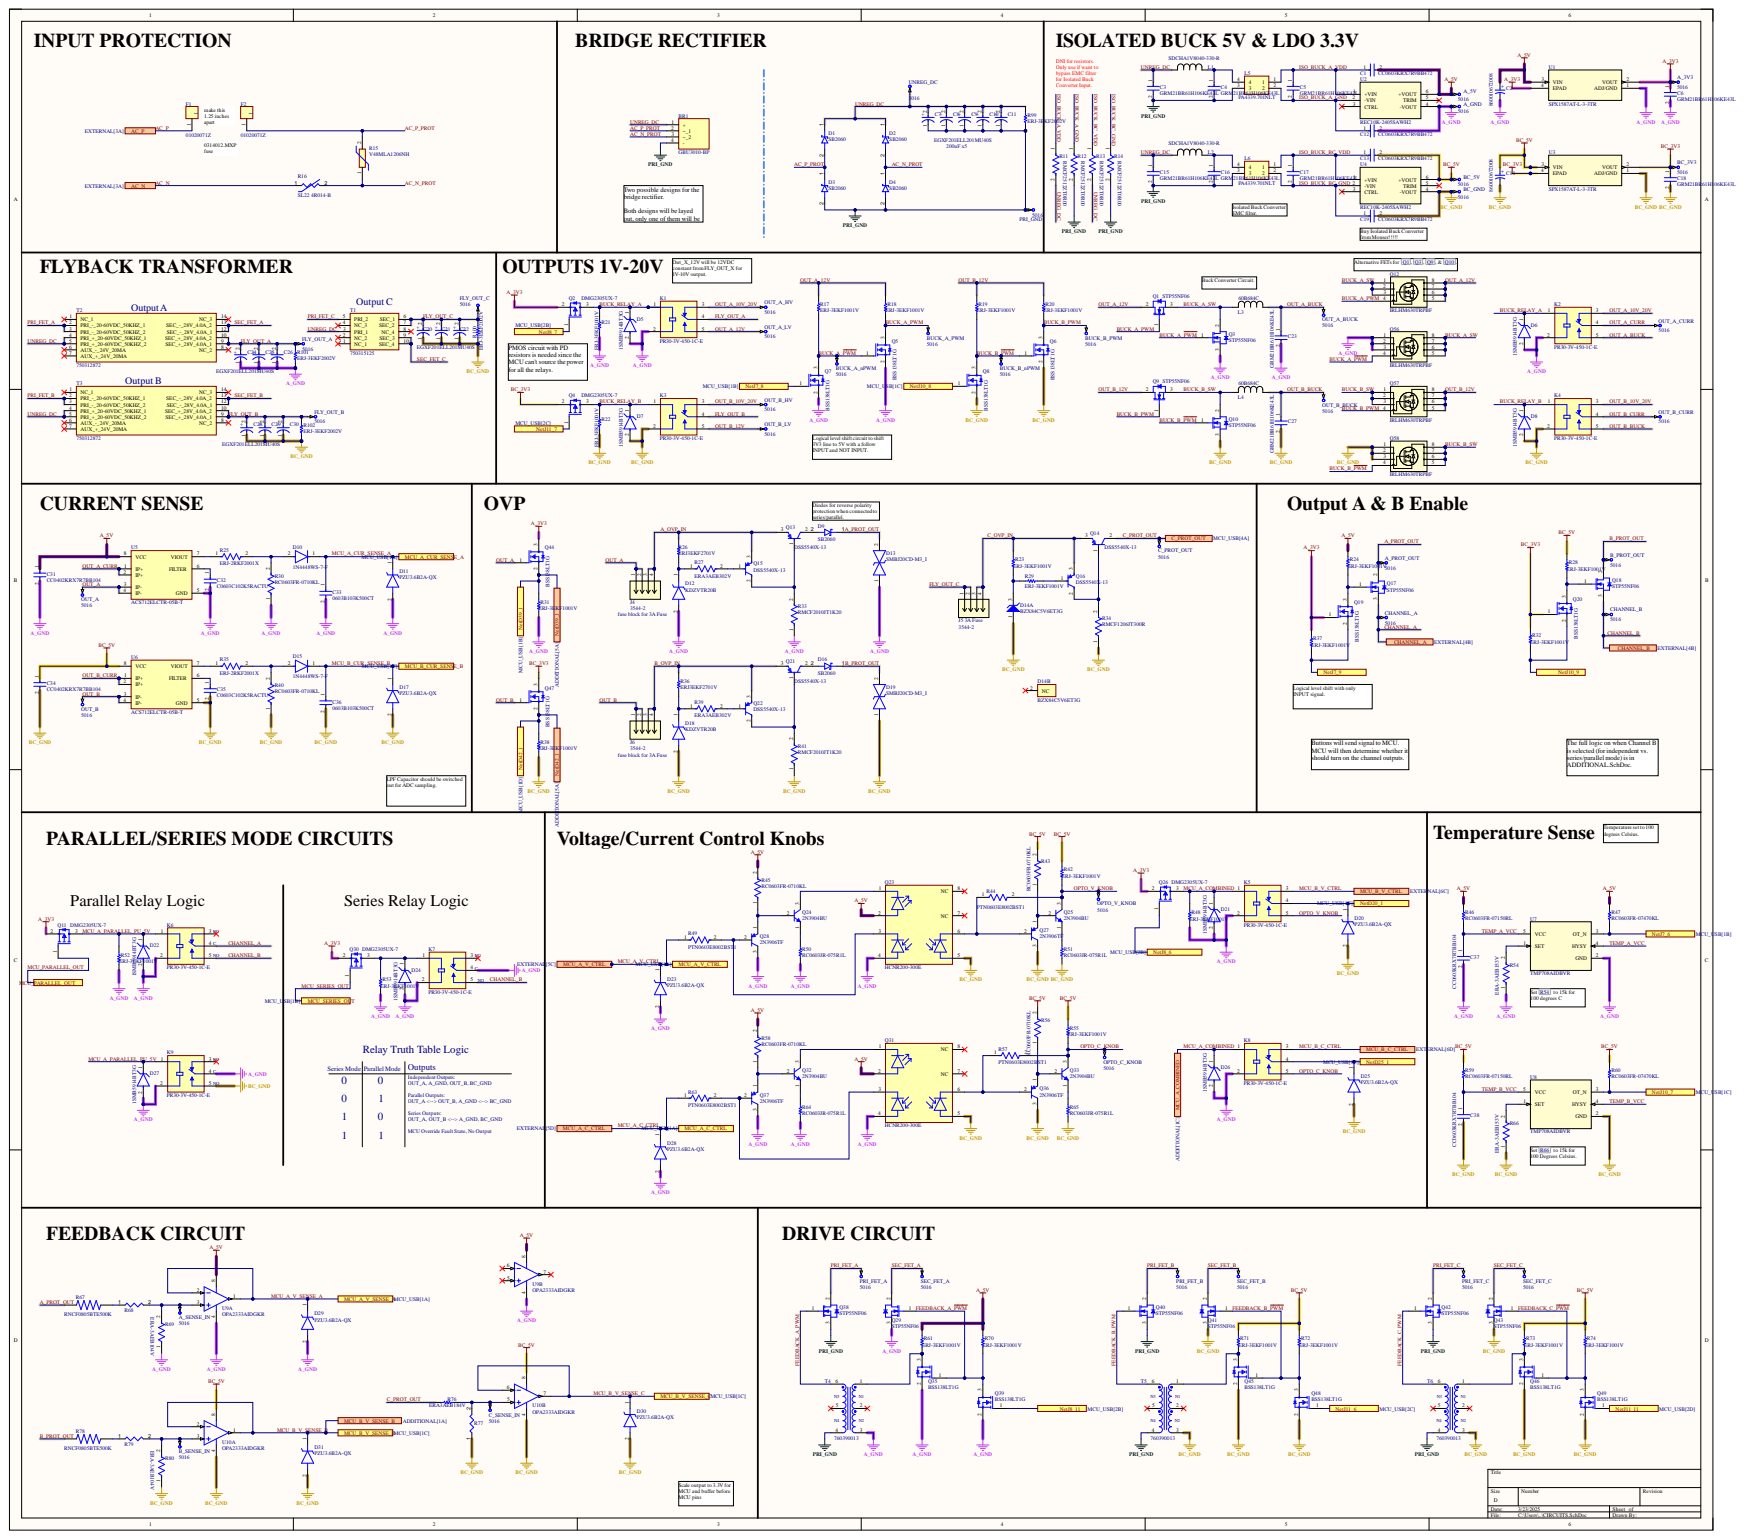
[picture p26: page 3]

DNI for resistors.
Only use if want to
bypass EMC filter
for Isolated Buck
Converter Input.

Two possible designs for the
bridge rectifier.

Both designs will be layed
out, only one of them will be
populated.

Buy Isolated Buck Converter
from Mouser!!!!!

PMOS circuit with PD
resistors is needed since the
MCU can't source the power
for all the relays.

Logical level shift circuit to shift
3V3 line to 5V with a follow
INPUT and NOT INPUT.

Diodes for reverse polarity
protection when connected to
series/parallel.

Logical level shift with only
INPUT signal.

Buttons will send signal to MCU.
MCU will then determine whether it
should turn on the channel outputs.

The full logic on when Channel B
isselected (for independent vs.
series/parallel mode) isin
ADDITIONAL.SchDoc.

LPF Capacitor should be switched
out for ADC sampling.

PARALLEL/SERIES MODE CIRCUITS

Voltage/Current Control Knobs

Relay Truth Table Logic

MCU Override Fault State, No Output

Scale output to 3.3V for
MCU and buffer before
MCU pins

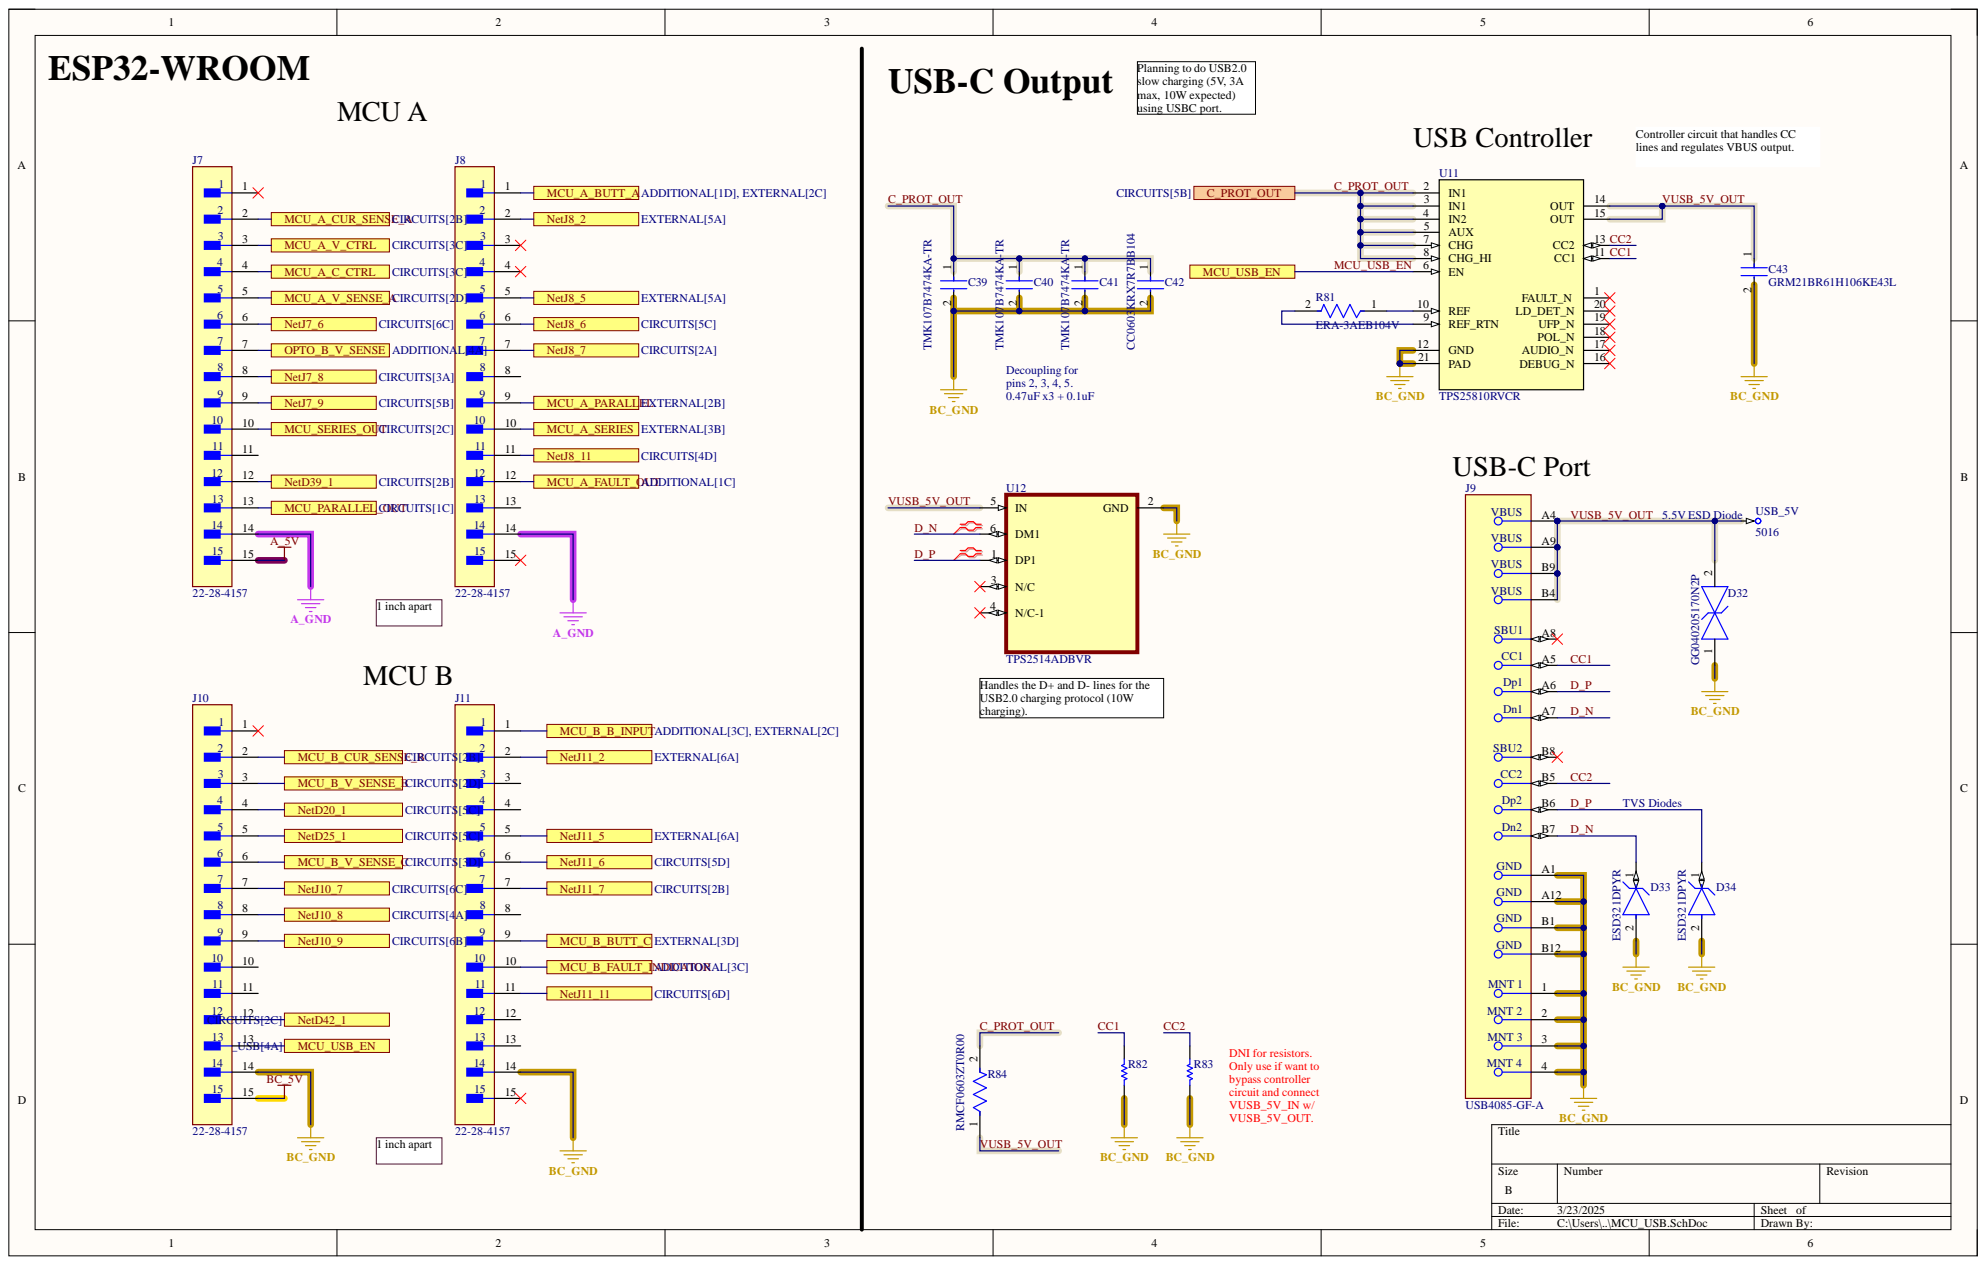
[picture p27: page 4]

Controller circuit that handles CC
lines and regulates VBUS output.

CHG 7
CHG_HI 8 | CC1

MCU_USB_EN | MCU_USB_EN | EN 6

Handles the D+ and D- lines for the
USB2.0 charging protocol (10W
charging).

DNI for resistors.
Only use if want to
bypass controller
circuit and connect
VUSB_5V_IN w/

Date: 3/23/2025 | Sheet of
File: C:\Users\..\MCU_USB.SchDoc | Drawn By:

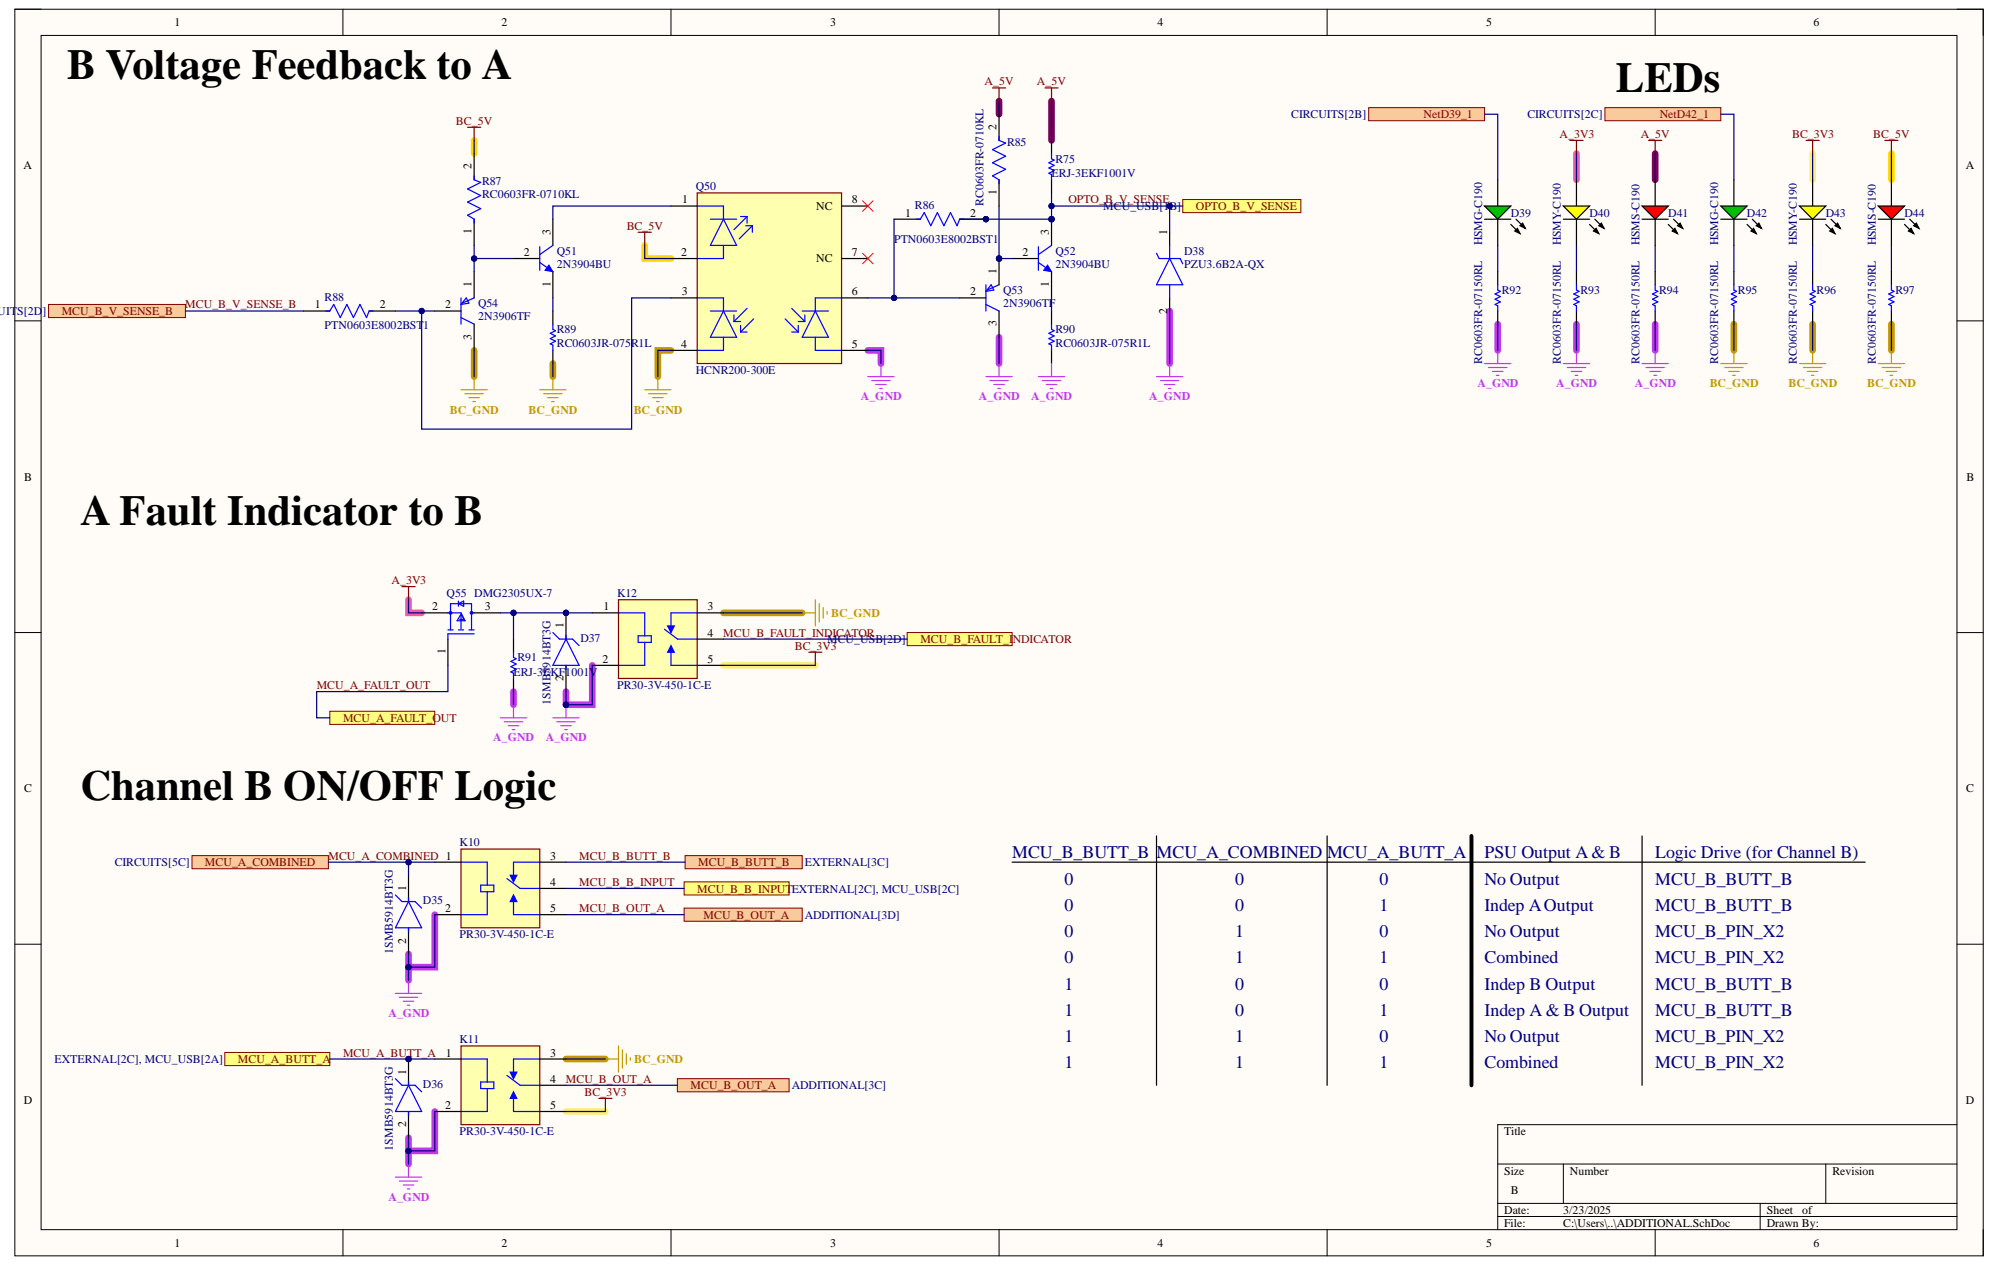
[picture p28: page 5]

Channel B ON/OFF Logic

Size B | Number | Revision

Date: 3/23/2025 | Sheet of
File: C:\Users\..\ADDITIONAL.SchDoc | Drawn By:
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

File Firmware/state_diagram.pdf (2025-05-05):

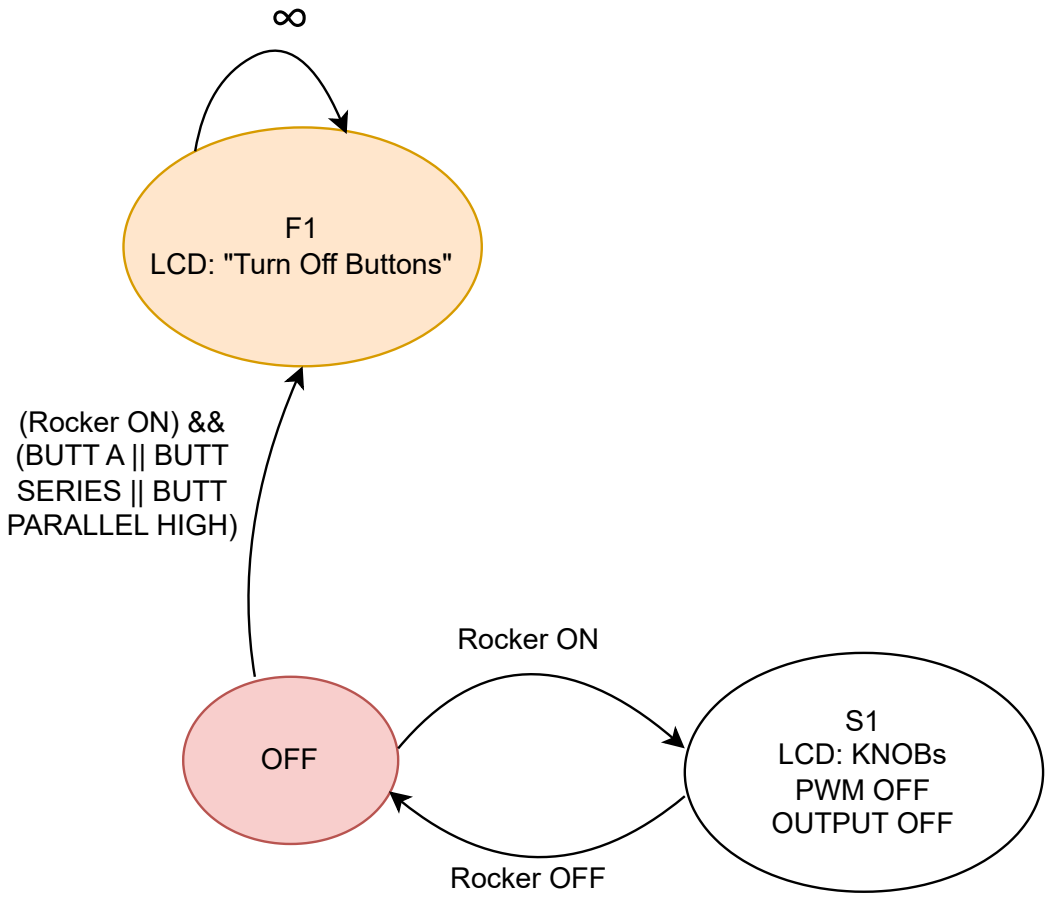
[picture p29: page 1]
OFF; Rocker ON; Rocker OFF; (Rocker ON) && (BUTT A || BUTT SERIES || BUTT PARALLEL HIGH); S1 LCD: KNOBs PWM OFF OUTPUT OFF

LCD: "Turn Off Buttons"

Rocker OFF

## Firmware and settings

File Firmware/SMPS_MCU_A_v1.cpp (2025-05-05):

// MCU A
// Switch Mode Power Supply - Senior Projects
// Azra Rangwala, Ilona Lameka, Ridwan Hussain

// Things to be adjusted during testing:
// frequency/resolution of PWM
// tolerance values
// time delays
// voltage and current sense calculations
// PWM calculations

// round the sense and knob float values to 3 decimal points
// serial monitor


#include <Arduino.h>
#include <LiquidCrystal_I2C.h>

// ADC Pins
const int CUR_SENSE = 36; // MCU_A_ADC1_C0
const int V_KNOB  = 39; // MCU_A_ADC1_C3
const int C_KNOB = 34; // MCU_A_ADC1_C6
const int VOL_SENSE = 35; // MCU_A_ADC1_C7
const int B_FEEDBACK = 33; // MCU_A_ADC1_C5

// GPIO Input Pins
const int TEMP = 32; // MCU_A_GPIO32
const int A_FUSE = 12; // MCU_A_GPIO12
const int A_BUTT = 23; // MCU_A_GPIO23
const int PARALLEL_BUTT = 17; // MCU_A_GPIO17
const int SERIES_BUTT = 16; // MCU_A_GPIO16

// GPIO Output Pins
const int BUCK = 25; // MCU_A_GPIO25
const int OUT_ENABLE = 26; // MCU_A_GPIO26
const int SERIES_RELAY = 27; // MCU_A_GPIO27
const int PARALLEL_RELAY = 13; // MCU_A_GPIO13
const int KNOBS = 19; // MCU_A_GPIO19
const int HV_LV_OUT = 18; // MCU_A_GPIO18
const int DRIVE = 4; // MCU_A_GPIO4
const int FLT_ALERT = 2; // MCU_A_GPIO2

void dominos (void*); // Core 0
void subway (void*);  // Core 1
void death (void*);   // Core 1
void lcdScreen(float, float);
void readKnobs();
void readSense();
void IRAM_ATTR isrTemp();
void IRAM_ATTR onSetupTimer();
void IRAM_ATTR onOutputTimer();
void flyDrive(float);
void buckDrive();

int lcdColumns = 16;
int lcdRows = 2;
LiquidCrystal_I2C lcd(0x27, lcdColumns, lcdRows); 

float gbl_vPotCalc, gbl_cPotCalc, gbl_vSenseCalc, gbl_cSenseCalc; //set to 0?
int gbl_stateA, gbl_drivePWM, gbl_buckPWM;
int gbl_prevStateA = 0;
int gbl_deathOnce = 0;
hw_timer_t* setupTimer = NULL;
hw_timer_t* outputTimer = NULL;

volatile bool interrupt = false;
volatile int faultState;
enum fault{OVERTEMP, SETUPOVERTIME, OUTPUTOVERTIME,  OVERCURRENT, BLOWNFUSE};

TaskHandle_t domTaskHandle = NULL;
TaskHandle_t subTaskHandle = NULL;
TaskHandle_t deathTaskHandle = NULL;

void setup() 
{
  Serial.begin (115200);
  Serial.println("MCU Restarting...");
  delay(100);
  lcd.init();                  
  lcd.backlight();

  pinMode(A_BUTT, INPUT);
  pinMode(PARALLEL_BUTT, INPUT);
  pinMode(SERIES_BUTT, INPUT);
  
  pinMode(TEMP, INPUT);
  attachInterrupt(TEMP, isrTemp, ONLOW);

  pinMode(A_FUSE, INPUT);

  ledcSetup(0, 42000, 10); //42kHz for Transformer
  ledcAttachPin(DRIVE, 0);

  ledcSetup(1, 35000, 10); //35kHz for buck
  ledcAttachPin(BUCK, 1);

  pinMode(OUT_ENABLE, OUTPUT);
  pinMode(HV_LV_OUT, OUTPUT);

  setupTimer = timerBegin(0,80, true);  // State S2 Timer
  timerAttachInterrupt(setupTimer, &onSetupTimer, true);
  timerAlarmWrite(setupTimer, 30000000, false); //30s

  outputTimer = timerBegin(1,80, true); // State S3 Timer
  timerAttachInterrupt(outputTimer, &onOutputTimer, true);
  timerAlarmWrite(outputTimer, 10000000, false); //10s

  // False Start Prevention
  if (digitalRead(A_BUTT) || digitalRead(PARALLEL_BUTT) || digitalRead(SERIES_BUTT))
  {
    while(1)
    {
      lcd.setCursor(0, 0);
      lcd.print("Turn Off Buttons");
      lcd.setCursor(0, 1);
      lcd.print("Restart SMPS               ");
    }
  }
  xTaskCreatePinnedToCore(dominos, "Dominatrix", 2048, NULL, 2, &domTaskHandle, 0);
  xTaskCreatePinnedToCore(subway, "Sub", 2048, NULL, 2, &subTaskHandle, 1);
}

// Always running on Core 0
// Output + Interrupt Sensing
void dominos (void* pvParameters) {
  for (;;) {
    readSense();
    if (interrupt && !gbl_deathOnce) // Happens only once 
    {
      vTaskDelete(subTaskHandle);
      vTaskDelay(pdMS_TO_TICKS(5));
      xTaskCreatePinnedToCore(death, "death", 2048, NULL, 8, &deathTaskHandle, 1);
      gbl_deathOnce = 1; // Restart MCU to get gbl_deathOnce = 0
    }
    vTaskDelay(pdMS_TO_TICKS(5)); // Feeding the dog
  }
}


void subway(void *pvParameters)
{
  for (;;)
  {
    Serial.println("subway");
    gbl_stateA = digitalRead(A_BUTT);
    if(gbl_stateA == 0)
    {
      ledcWrite(0, 0); //Drive
      ledcWrite(1, 0); //Buck
      digitalWrite(HV_LV_OUT, 1);
      digitalWrite(OUT_ENABLE, 0);
      readKnobs();
      lcdScreen(gbl_vPotCalc, gbl_cPotCalc);
      gbl_prevStateA = 0;
      vTaskDelay(pdMS_TO_TICKS(10));
    }
    else if((gbl_stateA == 1) && (gbl_prevStateA == 0))  // possibly two timers HV vs LV timer
    {
      timerRestart(setupTimer);
      timerAlarmEnable(setupTimer);
      if (gbl_vPotCalc > 10)
      {
        flyDrive(gbl_vPotCalc);
      }
      else
      {
        flyDrive(12);
        if (digitalRead(A_BUTT) && !interrupt)
        {
          digitalWrite(HV_LV_OUT, 0);
        }
        buckDrive();
      }
      timerAlarmDisable(setupTimer);
      gbl_prevStateA = 1;
    }
    else
    {
      Serial.println("s3");
      digitalWrite(OUT_ENABLE, 1);
      lcdScreen(gbl_vSenseCalc, gbl_cSenseCalc);
      // Fuse Check
      if (digitalRead(A_FUSE) && !(gbl_vSenseCalc > 0)) //check fi this actually works
      {
        faultState = BLOWNFUSE;
        interrupt = true;
      }
      // Current Check
      if ((gbl_cSenseCalc - gbl_cPotCalc) > 0.01) // if big difference in curret, kill immediately, if its below 20 mA, wait, then decide to kill or not
      {
        vTaskDelay(pdMS_TO_TICKS(15)); //delay to make sure its not a current spike //change delay later
        if ((gbl_cSenseCalc - gbl_cPotCalc) > 0.01)
        {
          faultState = OVERCURRENT;
          interrupt = true;
        }
      }
      // Voltage Check
      if (abs(gbl_vPotCalc-gbl_vSenseCalc) > 0.05) //check current in fly and drive while loops, die if over current
      {
        timerRestart(outputTimer);
        timerAlarmEnable(outputTimer);
        if (gbl_vPotCalc > 10)
        {
          Serial.println("trying");
          flyDrive(gbl_vPotCalc);
        }
        else
        {
          buckDrive();
        }
        timerAlarmDisable(outputTimer);
      }
      
      vTaskDelay(pdMS_TO_TICKS(15));
    }
  }
}

void readKnobs()
{
  // Getting the ADC Knob Values
  int vPotTotal = 0;
  int cPotTotal = 0;
  for (int i = 0; i < 50; i++) // Getting muliple samples due to ADC fluctuations
  {
    vPotTotal += analogRead(V_KNOB);
    cPotTotal += analogRead(C_KNOB);
    vTaskDelay(pdMS_TO_TICKS(1));
  }
  int vPot = vPotTotal / 50; 
  gbl_vPotCalc = ((vPot / 4095.0) * 19.0) + 1;

  int cPot = cPotTotal / 50;
  gbl_cPotCalc = (cPot / 4095.0) * 3.0;
}

void readSense()
{
  int cSenseTotal = 0;

  for (int i = 0; i < 100; i++) // Getting muliple samples due to ADC fluctuations
  {
    cSenseTotal += analogRead(CUR_SENSE);
    vTaskDelay(pdMS_TO_TICKS(1));
  }

  int vSense = analogRead(VOL_SENSE);
  gbl_vSenseCalc = ((vSense / 4095.0) * 20.0); // math might have to change for v and c

  int cSense = cSenseTotal / 100;
  gbl_cSenseCalc = (cSense * 0.00618) - 12.5;
}

void lcdScreen(float v, float c) 
{   
    lcd.setCursor(0, 0);
    char vDisplay[6];  
    dtostrf(v, 4, 2, vDisplay); 
    lcd.print(String("Voltage: ") + String(vDisplay) + String(" V       "));

    lcd.setCursor(0,1);
    char cDisplay[6];  
    dtostrf(c, 4, 2, cDisplay); 
    lcd.print(String("Current: ") + String(cDisplay) + String(" A"));
}

void IRAM_ATTR isrTemp() 
{
  detachInterrupt(TEMP);
  faultState = OVERTEMP;
  interrupt = true;
}

void IRAM_ATTR onSetupTimer()
{
  timerAlarmDisable(setupTimer);
  timerDetachInterrupt(setupTimer);
  faultState = SETUPOVERTIME;
  interrupt = true;
}

void IRAM_ATTR onOutputTimer()
{
  timerAlarmDisable(outputTimer);
  timerDetachInterrupt(outputTimer);
  faultState = OUTPUTOVERTIME;
  interrupt = true;
}

void death (void* pvParameters)
{
  for (;;)
  {
    Serial.println("dying");
    detachInterrupt(TEMP);
    ledcWrite(0, 0);
    ledcWrite(1, 0);
    digitalWrite(OUT_ENABLE, 0); 
    digitalWrite(HV_LV_OUT, 1);
    lcd.setCursor(0, 0);
    Serial.println("this again");
    switch(faultState)
    {
      case OVERTEMP:
      {
        lcd.print("Over Temperature");
        break;
      }
      case SETUPOVERTIME:
      {
        lcd.print("Setup Overtime    ");
        break;
      }
      case OUTPUTOVERTIME:
      {
        lcd.print("Output Overtime    ");
        break;
      }
      case OVERCURRENT:
      {
        lcd.print("Over Current    ");
        break;
      }
      case BLOWNFUSE:
      {
        lcd.print("Blown Fuse       ");
        break;
      }
    
    }
    lcd.setCursor(0, 1);
    lcd.print(String("Restart SMPS: E") + String(faultState) + String("       "));
    vTaskDelay(pdMS_TO_TICKS(1000));
  }
}

// fix math
// add a min and max duty cycle clamping
// soft start 

// Controls the Flyback PWM signals
void flyDrive(float vComp) 
{
  if (gbl_prevStateA == 0) // Only allows change to the PWM rate if a new Pot Value was given
  {
    gbl_drivePWM = (((vComp - 10) / 10) * 154) + 256; //fix math
    ledcWrite(0, gbl_drivePWM);
  }
  float err = vComp - gbl_vSenseCalc;
  do
  {
    gbl_drivePWM =  ((err / 10) * 500); //fix math
    ledcWrite(0, gbl_drivePWM);
    Serial.println(gbl_drivePWM);
    vTaskDelay(pdMS_TO_TICKS(2));
    err = vComp - gbl_vSenseCalc;
  }
  while(!interrupt && (abs(err) > 0.05) && digitalRead(A_BUTT));
  vTaskDelay(pdMS_TO_TICKS(5));
}

// Controls the Buck Converter PWM signals
//soft start
void buckDrive() 
{
  if (gbl_prevStateA == 0)
  {
    gbl_buckPWM = (((gbl_vPotCalc - 10) / 10) * 154) + 256;
    ledcWrite(1, gbl_buckPWM);
  }
  float err = gbl_vPotCalc - gbl_vSenseCalc;
  do
  {
    gbl_buckPWM = ceil((((err / 10) * 154) + 256));
    ledcWrite(1, gbl_buckPWM);
    Serial.println("buck");
    Serial.println(gbl_buckPWM);
    vTaskDelay(pdMS_TO_TICKS(2));
    err = gbl_vPotCalc - gbl_vSenseCalc;
  }
  while(!interrupt && (abs(err) > 0.05) && digitalRead(A_BUTT));
}

void loop() {
  // Empty loop necessary for FreeRTOS
}

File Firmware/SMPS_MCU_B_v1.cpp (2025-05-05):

// MCU B
// Switch Mode Power Supply - Senior Projects
// Azra Rangwala, Ilona Lameka, Ridwan Hussain

#include <Arduino.h>
#include <LiquidCrystal_I2C.h>

// ADC Pins
const int CUR_SENSE = 36; // MCU_B_ADC1_C0
const int B_VOL_SENSE  = 39; // MCU_B_ADC1_C3
const int V_KNOB = 34; // MCU_B_ADC1_C6
const int C_KNOB = 35; // MCU_B_ADC1_C7
const int USB_VOL_SENSE = 32; // MCU_B_ADC1_C4

// GPIO Input Pins
const int TEMP = 33; // MCU_B_GPIO33
const int B_FUSE = 12; // MCU_B_GPIO12
const int B_BUTT = 23; // MCU_B_GPIO23
const int USB_BUTT = 17; // MCU_B_GPIO17
const int FLT_ALERT = 16; // MCU_B_GPIO16


// GPIO Output Pins
const int BUCK = 25; // MCU_B_GPIO25
const int OUT_ENABLE = 26; // MCU_B_GPIO26
const int USB_ENABLE = 13; // MCU_B_GPIO13
const int B_DRIVE = 19; // MCU_B_GPIO19
const int HV_LV_OUT = 18; // MCU_B_GPIO18
const int USB_DRIVE = 4; // MCU_B_GPIO4

void dominos (void*);
void subway (void*);
void death (void*);
void lcdScreen(float, float);
void readKnobs();
void readSense();
void IRAM_ATTR isrTemp();
void IRAM_ATTR onSetupTimer();
void IRAM_ATTR onOutputTimer();
void flyDrive(float);
void buckDrive();

int lcdColumns = 16;
int lcdRows = 2;
LiquidCrystal_I2C lcd(0x27, lcdColumns, lcdRows); 

float vPotCalc, cPotCalc, vSenseCalc, cSenseCalc; //set to 0?
int stateB, B_drivePWM, buckPWM;
int prevStateB = 0;
int f1 = 0;
hw_timer_t* setupTimer = NULL;
hw_timer_t* outputTimer = NULL;

volatile bool interrupt = false;
volatile int faultState;
enum fault{OVERTEMP, SETUPOVERTIME, OUTPUTOVERTIME,  OVERCURRENT, BLOWNFUSE};

TaskHandle_t domTaskHandle = NULL;
TaskHandle_t subTaskHandle = NULL;
TaskHandle_t deathTaskHandle = NULL;

void setup() 
{
  Serial.begin (115200);
  Serial.println("MCU Restarting...");
  delay(100);
  lcd.init();                  
  lcd.backlight();

  pinMode(B_BUTT, INPUT);
  pinMode(USB_BUTT, INPUT);
  pinMode(B_FUSE, INPUT);
  
  pinMode(TEMP, INPUT);
  attachInterrupt(TEMP, isrTemp, ONLOW);

  ledcSetup(0, 50000, 10);
  ledcAttachPin(B_DRIVE, 0);

  ledcSetup(1, 50000, 10);
  ledcAttachPin(BUCK, 1);

  pinMode(OUT_ENABLE, OUTPUT);
  pinMode(HV_LV_OUT, OUTPUT);

  setupTimer = timerBegin(0,80, true);
  timerAttachInterrupt(setupTimer, &onSetupTimer, true);
  timerAlarmWrite(setupTimer, 30000000, false); //30s

  outputTimer = timerBegin(1,80, true);
  timerAttachInterrupt(outputTimer, &onOutputTimer, true);
  timerAlarmWrite(outputTimer, 10000000, false); //10s

  // False Start Prevention
  if (digitalRead(B_BUTT) || digitalRead(USB_BUTT))
  {
    while(1)
    {
      lcd.setCursor(0, 0);
      lcd.print("Turn Off Buttons");
    }
  }
  xTaskCreatePinnedToCore(dominos, "Dominatrix", 2048, NULL, 2, &domTaskHandle, 0);
  xTaskCreatePinnedToCore(subway, "Sub", 2048, NULL, 2, &subTaskHandle, 1);
}

void dominos (void* pvParameters) {
  for (;;) {
    readSense();
    if (interrupt && !f1)
    {
      vTaskDelete(subTaskHandle);
      vTaskDelay(pdMS_TO_TICKS(5));
      xTaskCreatePinnedToCore(death, "death", 2048, NULL, 8, &deathTaskHandle, 1);
      f1 = 1;
    }
    vTaskDelay(pdMS_TO_TICKS(5)); // Feeding the dog
  }
}


void subway(void *pvParameters)
{
  for (;;)
  {
    Serial.println("subway");
    stateB = digitalRead(B_BUTT);
    if(stateB == 0)
    {
      ledcWrite(0, 0); //Drive
      ledcWrite(1, 0); //Buck
      digitalWrite(HV_LV_OUT, 0);
      digitalWrite(OUT_ENABLE, 0);
      readKnobs();
      lcdScreen(vPotCalc, cPotCalc);
      prevStateB = 0;
      vTaskDelay(pdMS_TO_TICKS(10));
    }
    else if((stateB == 1) && (prevStateB == 0))
    {
      timerRestart(setupTimer);
      timerAlarmEnable(setupTimer);
      if (vPotCalc > 10)
      {
        flyDrive(vPotCalc);
      }
      else
      {
        flyDrive(12);
        if (digitalRead(B_BUTT) && !interrupt)
        {
          digitalWrite(HV_LV_OUT, 1);
        }
        buckDrive();
      }
      timerAlarmDisable(setupTimer);
      prevStateB = 1;
    }
    else
    {
      Serial.println("s3");
      digitalWrite(OUT_ENABLE, 1);
      lcdScreen(vSenseCalc, cSenseCalc);
      if ((cSenseCalc - cPotCalc) > 0.01) 
      {
        vTaskDelay(pdMS_TO_TICKS(15)); //delay to make sure its not a current spike
        if ((cSenseCalc - cPotCalc) > 0.01)
        {
          faultState = OVERCURRENT;
          interrupt = true;
        }
      }
      if (abs(vPotCalc-vSenseCalc) > 0.05)
      {
        timerRestart(outputTimer);
        timerAlarmEnable(outputTimer);
        if (vPotCalc > 10)
        {
          Serial.println("trying");
          flyDrive(vPotCalc);
        }
        else
        {
          buckDrive();
        }
        timerAlarmDisable(outputTimer);
      }
      if (digitalRead(B_FUSE) && (vSenseCalc < 0.1)) //change v value
      {
        faultState = BLOWNFUSE;
        interrupt = true;
      }
      vTaskDelay(pdMS_TO_TICKS(15));
    }
  }
}

void readKnobs()
{
  // Getting the ADC Knob Values
  int vPotTotal = 0;
  int cPotTotal = 0;
  for (int i = 0; i < 50; i++) // Getting muliple samples due to ADC fluctuations
  {
    vPotTotal += analogRead(V_KNOB);
    cPotTotal += analogRead(C_KNOB);
    vTaskDelay(pdMS_TO_TICKS(1));
  }
  int vPot = vPotTotal / 50; 
  vPotCalc = ((vPot / 4095.0) * 19.0) + 1;

  int cPot = cPotTotal / 50;
  cPotCalc = (cPot / 4095.0) * 3.0;
}

void readSense()
{
  int vSense = analogRead(B_VOL_SENSE);
  vSenseCalc = ((vSense / 4095.0) * 19.0); // math might have to change for v and c

  int cSense = analogRead(CUR_SENSE);
  cSenseCalc = (cSense / 4095.0) * 3.0;
}

void lcdScreen(float v, float c) 
{   
    lcd.setCursor(0, 0);
    char vDisplay[6];  
    dtostrf(v, 4, 2, vDisplay); 
    lcd.print(String("Voltage: ") + String(vDisplay) + String(" V       "));

    lcd.setCursor(0,1);
    char cDisplay[6];  
    dtostrf(c, 4, 2, cDisplay); 
    lcd.print(String("Current: ") + String(cDisplay) + String(" A"));
}

void IRAM_ATTR isrTemp() 
{
  detachInterrupt(TEMP);
  faultState = OVERTEMP;
  interrupt = true;
}

void IRAM_ATTR onSetupTimer()
{
  timerAlarmDisable(setupTimer);
  timerDetachInterrupt(setupTimer);
  faultState = SETUPOVERTIME;
  interrupt = true;
}

void IRAM_ATTR onOutputTimer()
{
  timerAlarmDisable(outputTimer);
  timerDetachInterrupt(outputTimer);
  faultState = OUTPUTOVERTIME;
  interrupt = true;
}
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

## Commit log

2025-02-15 Added LTSpice Simulation Folder
    Added LTSpice Simulation Folder for Outdated SMPS sim, Buck Converter, and Logical Level Shifter.
2025-02-16 Redid Logical Level Shift Sim
    Redid Logical Level Shift Sim so there's a less complicated follower circuit since not all the logical levels needs to be inverted.
2025-02-16 Updated schematic.
2025-02-17 Updated Buck Converter Circuit
    Added single NMOS logic shifter
    Adjusted L and C value so that PWM can output 1V - 10V consistently from 100Ohm to 100kOhm range.
2025-02-25 Updated Buck Converter and Logical Level Shift
    Updated Buck Converter and Logical Level Shift.
    Buck converter has a sync and async simulation with additional notes.
2025-02-25 Finalized changed on Buck Converter.
    Finalized changed on Buck Converter. Made things look nicer and adjusted PU resistor to something more realistic based on power ratings.
2025-03-16 Uploaded correct Schematic Page 3 MCU & USB image.
2025-03-16 Updating image link for page 3 schematic.
2025-03-23 Fixed Buck Converter Sim
    Fixed Buck Converter Sim. Needed to use IRLHM630 instead of the STP55NF06.
2025-03-23 Final Board Files
    Final Board Files
2025-03-24 Added SMPS.zip Altium Files & board information report.
    Added SMPS.zip Altium Files & board information report.
2025-04-01 Update SMPS Testing Procedure.md
    Channel A Temperature Sensor
2025-04-03 channel A 5V and 3V3
2025-04-07 PWM Tests
2025-04-07 Missing resistors for buttons
2025-04-07 PWM Testing at 10kHz and 50kHz
2025-04-07 PWM Testing Results
2025-04-07 Input Button Testing
2025-04-11 Update SMPS Testing Procedure.md
    Added changes to Channel A with the Iso Gate Driver instead of feedback transformer.
2025-04-22 Buck Testing with Transformer
2025-04-24 Fuse LED
